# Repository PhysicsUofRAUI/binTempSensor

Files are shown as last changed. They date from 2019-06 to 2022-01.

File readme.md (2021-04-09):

# Bin Temperature Sensor
This project is a gadget to monitor the temperature in a grain bin. This is important because when grain heats it can spoil and a farmer can lose lots of money. The current iteration is the cheapest when 4 bins are wired up and costs about $140 per bin. That cost can be contrasted with the current bin monitoring systems which can cost up to $5000 a bin. The next iteration will focus on lowering the per bin cost for when more than 4 bins are wired up, and the iteration after that will integrate Arduino Cloud into the project, so that all collected data can be stored for later use.

## Main Hardware
### Arduino MKR 1400
This will be the Arduino that will send the alerts to the farmer and possibly one day send data to the Arduino Cloud. At the moment the code is designed to be controlled soley by the MKR 1400, but in the next iteration it will recieve alerts from regular Arduinos.

### Temperature Sensor
The DHT 22 or the DFR0198 sensor is currently being used as the sensor. Three of them are needed to monitor one bin.

### RF Link kits
The next iteration of the code will have the MKR 1400 recieve alerts from regular Arduinos about the sensors in the regular Arduinos.

### Arduino Mega
This will be used in the second iteration to control the sensors in the bin and send the alerts or data to the MKR 1400. 

## Implementations
### Current Implementation
The current iteration is simple, and only uses the MKR 1400 and the DHT 22 sensors or DFR0198 sensors. It will connect to the cloud and will request data every 15 minutes and if the temperature has changed the cloud will be updated. The frequency of readings can be reduced to save on data charges. This iteration is using the code located in code/ArduinoCloud.

#### Cost
Below I will outline the cost of how much the current implementation would cost for four large bins (about 30ft high). If your bins are larger or smaller you would either need to buy more or less wire, but it should not change the cost that much. The price of the wire put in is what I have got, but your price will probably be different.

#### Hardware Costs
##### With AM2302
| Item | Price of One | Number Needed | Total Cost |
| --- |:---:| ---:| ---:|
| MKR 1400 | [$103.41](https://www.digikey.ca/en/products/detail/arduino/ABX00018/8135631) | 1 | $103.41 |
| DHT 22 | [$21.81](https://www.digikey.ca/en/products/detail/adafruit-industries-llc/393/5356714?s=N4IgTCBcDaIIIFkAEYDMAGCBdAvkA) | 12 | $261.72 |
| Junction Box | [$25.99](https://www.amazon.ca/gp/product/B075DJQJVY/ref=ppx_yo_dt_b_asin_title_o00_s00?ie=UTF8&psc=1) | 1 | $25.99 |
| Wire (per foot) | Varies | 300 | $95 |
| Hologram Sim | [$5.00](https://store.hologram.io/store/) | 1 | $5.00 |
| Total | | | $491.12 |

Note that shipping was not included for any of this.

#### With DFR0198
| Item | Price of One | Number Needed | Total Cost |
| --- |:---:| ---:| ---:|
| MKR 1400 | [$103.41](https://www.digikey.ca/en/products/detail/arduino/ABX00018/8135631) | 1 | $103.41 |
| DFR0198 | [$10.03](https://www.digikey.ca/en/products/detail/dfrobot/DFR0198/7597054) | 12 | $120.36 |
| Junction Box | [$25.99](https://www.amazon.ca/gp/product/B075DJQJVY/ref=ppx_yo_dt_b_asin_title_o00_s00?ie=UTF8&psc=1) | 1 | $25.99 |
| Wire (per foot) | Varies | 300 | $95 |
| Hologram Sim | [$5.00](https://store.hologram.io/store/) | 1 | $5.00 |
| Total | | | $349.76 |

#### Monthly Costs
| Item | Price |
| --- |:---:|
| Arduino Cloud Account | [$9.00 CAD](https://store.arduino.cc/digital/create#) | 
| Hologram Data Costs | $11.80 CAD |
| Total | $20.8 |

Note: The data charges will probably be lower since this was calculated on costs when there was no grain in the bin and the temperature varies wildly then.

### Future Improvements
#### RF Link kits
The Arduino Mega has 54 digital pins so it can control many more bins than the MKR 1400 can, however, it cannot connect to the network. The RF link kit will allow the Mega to communication with the MKR 1400 and the MKR 1400 will be able to communicate with the network and send alerts.

#### Email Alerts
This is currently the focus of the work and it will entail the MKR GSM sending data to a third party, possibly IFTTT, which will then send out an email alerting the farmer to a temperature rise. 

# Contributing
Please anyone feel free to contribute. It would especially be appreciated if people with more experience on the hardware related, people involved on farms (like me :smiley:) who have experience to what is really needed to help production and save bushels, and people with experience writing software for this type of hardware.

All this being said I do want to stress that those thinking they don't know anything about this, but are still interested in the project please at least contact. We have almost no-one here and even if people don't think it they always have some sort of skill that could be used.

# Final Remarks
Hopefully this project becomes a success and maybe more like could be made!

Thanks for reading all this!

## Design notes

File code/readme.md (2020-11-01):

# Short Brief
This directory is meant to hold the code that will be deployed, or used to test the setup. Currently the deployment code is held in this very directory, instead of an inner directory, and the test code is held in the test directory. For this code to compile correctly it has to be run in the Arduino IDE. If the code is not run in the Arduino IDE the needed libraries will not be found please see the how-to docs to learn more.

## Deployment Code
### one_bin
This holds the code to control a single bin. Below is a table describing where Arduino is expecting all the sensors to be connected (a how-to doc will be written about sensor wiring).

| Pin | Location |
| --- | --- |
| 0 | Top of bin |
| 1 | Middle of bin |
| 2 | Bottom of bin |

### two_bins
This holds the code to control a two bins. Below is a table describing where Arduino is expecting all the sensors to be connected (a how-to doc will be written about sensor wiring).

| Pin | Location |
| --- | --- |
| 0 | Top of bin one |
| 1 | Middle of bin one |
| 2 | Bottom of bin one |
| 3 | Top of bin two |
| 4 | Middle of bin two |
| 5 | Bottom of bin two |

### three_bins
This holds the code to control a three bins. Below is a table describing where Arduino is expecting all the sensors to be connected (a how-to doc will be written about sensor wiring).

| Pin | Location |
| --- | --- |
| 0 | Top of bin one |
| 1 | Middle of bin one |
| 2 | Bottom of bin one |
| 3 | Top of bin two |
| 4 | Middle of bin two |
| 5 | Bottom of bin two |
| 6 | Top of bin three |
| 7 | Middle of bin three |
| 8 | Bottom of bin three |

### four_bins
This holds the code to control a four bins. Below is a table describing where Arduino is expecting all the sensors to be connected (a how-to doc will be written about sensor wiring).

| Pin  | Location |
| ---- | --- |
| 0 | Top of bin one |
| 1 | Middle of bin one |
| 2 | Bottom of bin one |
| 3 | Top of bin two |
| 4 | Middle of bin two |
| 5 | Bottom of bin two |
| 6 | Top of bin three |
| 7 | Middle of bin three |
| 8 | Bottom of bin three |
| 9 | Top of bin four |
| 10 | Middle of bin four  |
| 11 | Bottom of bin four  |

## Test Code
Currently there is only one test, and that one is a test of the custom library and this style of the code. A how-to doc will be included in the how_to_docs directory.

## Future Additions
When the new iterations are being developed new folders in the test directory will be included, and I will do my best to document what they are and what they are doing. Once deployment code has been developed for the new iterations new folders will appear to hold the deployment code so that the code for the different iterations are held separately.

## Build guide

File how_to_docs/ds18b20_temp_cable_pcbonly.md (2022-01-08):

# 1. Introduction
This how-to will hopefully explain to you how to create your own temperature cable to place within a bin using DS18B20 sensors. After completing the construction of the cables you can move on to put together the rest of the grain monitoring system outlined.

# 2. Needed skills, materials/tools, and parts
## 2.1 Skills
The only non-common/specialized skills needed to complete this how-to is hand soldering of wires and programming of Arduinos. A great tutorial on youtube can be seen here: https://www.youtube.com/watch?v=Zu3TYBs65FM. If you follow that guy you will solder better than I do.

For programming an Arduino I would recommend reading this article: If you have not done this before I would recommend reading the following article: https://www.digikey.ca/en/maker/blogs/2018/how-to-get-started-with-arduino.

## 2.2 Material/tools
You will need a standard fine tip **soldering iron** to do the soldering. I personally use a single temperature not so fine tipped soldering iron, but I should probably upgrade. Along with the soldering iron you will need **solder** I use 23 gauge solder, but a lower gauge would probably work.

You will also need a pair of **side cutters** to cut away the stray wires after assembling the board.

The last tool you will need is a pair of wire **strippers**.

## 2.3 Parts
- 4 DS18B20 sensors (https://www.digikey.ca/en/products/detail/adafruit-industries-llc/381/5875807)
- Some wire (https://www.homedepot.ca/product/southwire-18-3-fas-lvt-thermostat-wire-150m-brown/1000794341)
  - I used 60 ft of fire alarm cable for a 25ft tall bin

# 3. Assembly
## 3.1 Measure The Bin
The easiest way to do this is to measure the height of one ring and then count how many rings there are. In my case I measured one ring to be roughly 3.5 feet, and I counted 5 rings in total. That makes a total height of $3.5ft \times 5 = 17.5ft$.

To gauge how long the entire cable needs to be I estimated the height of the top to be 5ft to 8.5ft. That brings the total height estimate to 25ft so doubling that brings me to 50ft and then an extra 10ft gives some leeway to hook up the arduino later.

## 3.2 Decide where to place the sensors
Placing the sensors have to be done with some care. The top sensor should be in the top ring or lower so it is covered by the grain, and the bottom sensor needs to be somewhere around the start of the hopper but can not be at the bottom.

What I did initially was to place the bottom sensor first and then the space the other two 7ft away from each other. During operation it was realized that this did not give adequate coverage of the bin and it was decided to increase the amount of sensors to 4 and to place them 4ft apart.

Below is an outline of how my sensors should line up in the bin.

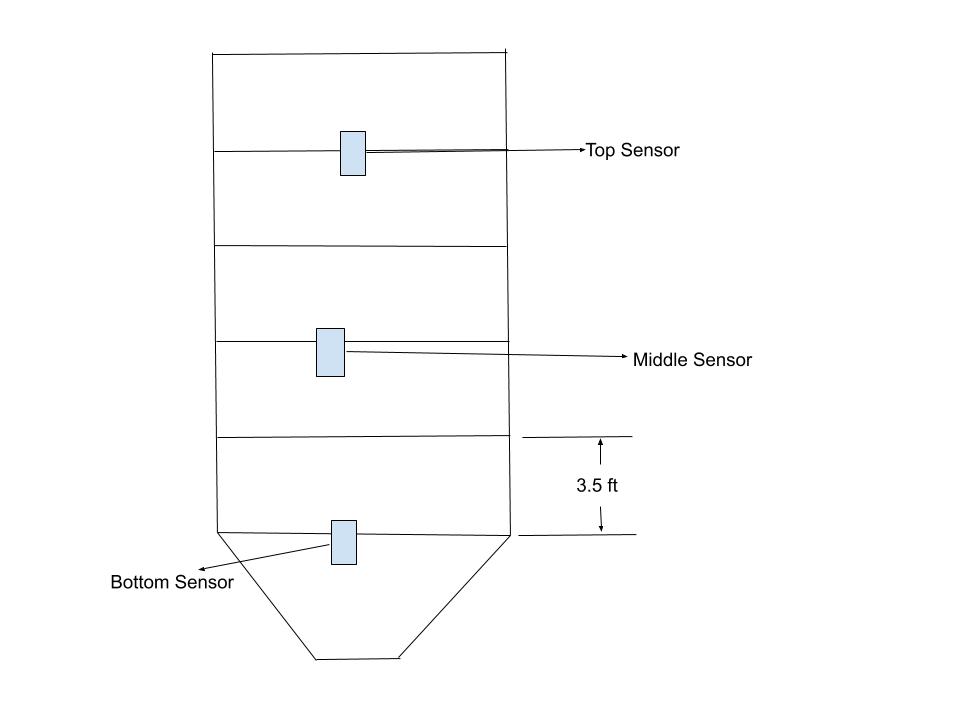
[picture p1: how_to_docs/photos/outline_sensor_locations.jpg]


## 3.3 Mark where the sensors go on the main cable
Before I started attaching the sensors I used a knife to mark the places where the sensors are to go. A photo can be seen below.

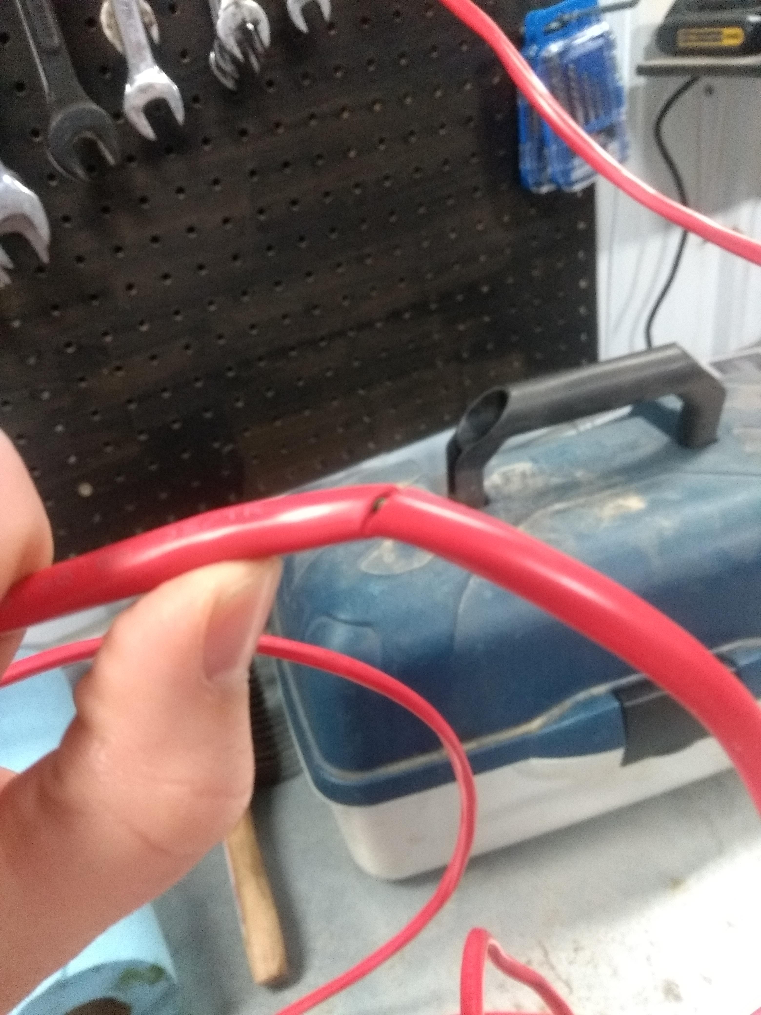
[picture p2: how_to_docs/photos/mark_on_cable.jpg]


When doing longer cables I would attach a sensor and then mark the next one just because it was getting to become cumbersome to deal with all the wire that was strewn around the shop.

## 3.4 Attach the sensors to the main cable
Before placing all the sensors on the cable it is advisable to slide three pieces of heat shrink (about 6 inches in length) onto the cable to be used later to cover up all the connections made while attaching the sensors.

### 3.4.1 Bottom Sensor
1. Strip the power (I used the red one) and the ground (I used the black one) just a enough so the sensor can be attached. To see the what the different colours of the DS18B20 sensors are I would go to the datasheet from that particular manufacturer. In the case of version linked above a table is provided below:

| Colour | Purpose |
| --- | --- |
| Blue | Ground  |
| Yellow | Data |
| Red | Power |

The only other colour I have seen is black for ground instead of blue.

2. Now strip the wire that will be used as the data pin.

3. Solder the black wire of the sensor to the ground.

4. Solder the red wire to the power.

5. Solder the last wire (yellow wire on my devices) to the conductor that will be used as the data wire.

6. Put some electrical tape around each of the solders.
  - Note: for this one heat shrink could be used, but for the following it could not

7. Apply the first heat shrink around the electrical connections. Do not heat the heat shrink until after the cable is tested in case something is wrong.



A photo of a DS18B20 sensor attached to the cable will be added later.

### 3.4.2 Middle and Top Sensor
1. Measure the decided amount of feet separating each sensor and mark the location.

2. Follow the steps done for the bottom sensor keeping in mind the sheathing will have to be cut away instead of stripped since it is in the middle of the cable.

Cable shown stripped in the middle.



The sensor soldered and attached in the middle.



The sensor tapped in the middle.





## 3.5 Test the Cable
### 3.5.1 Assemble the circuit
For this step you will need an assembled grain monitoring board, your freshly created cable, an MKR board, and a computer with the Arduino IDE installed. Plug the Arduino into the PCB and plug the cable into the female pluggable connector location with one of the male connectors (attach the male connector first). Below a photo shows the Arduino plugged in along with the male connector plugged into the female connector.

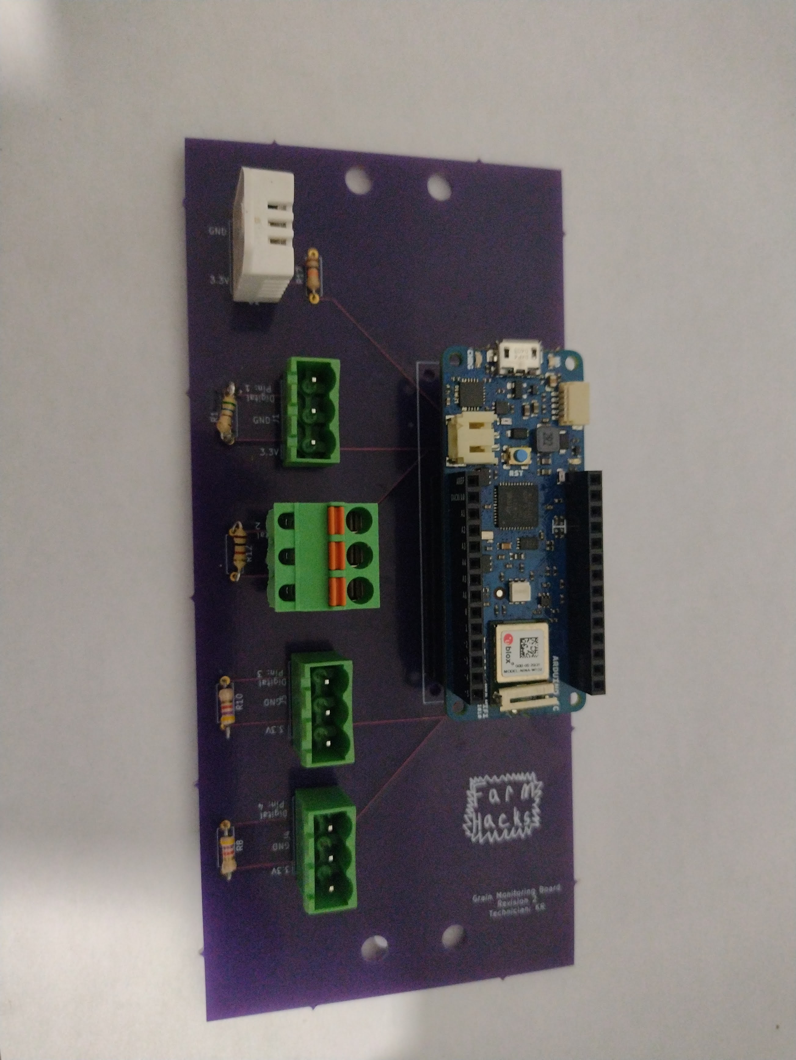
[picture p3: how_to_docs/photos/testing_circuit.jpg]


People more experienced with electronics can likely figure out other ways to assemble this circuit but I will not get into them here.

### 3.5.2 Edit Code
The code to be using can be found at code/testing_code. What needs to be added/changed is the device addresses on lines 24, 25, 26 and 27. Those lines are shown below:
```
DeviceAddress top = { 0x28, 0x63, 0x38, 0xF3, 0x4C, 0x20, 0x01, 0xD2 };
DeviceAddress middle_top = {  };
DeviceAddress middle_bottom = {  };
DeviceAddress bottom = {  };
```
The address labeled top is filled out as an example but it will have to be replaced with the address on the label that was on the top DS18B20s bag. Each of the other addresses will also have to be labeled.

### 3.5.3 Upload Code
Once the code is edited you will have to upload it to the Arduino.

### 3.5.4 Check the sensors
First open the serial monitor while the Arduino is plugged in to view the temperature the Arduino is reading. When it is open I would go and warm the individual sensors as they are running to ensure the sensors were placed in the correct locations.

## 3.6 Complete the Cable
If the testing went as planned take a heat gun (or a torch if you do not have one), and heat the heat shrink to seal the connections.

# 4. Conclusion
This concludes the tutorial of how to create the DS18B20 based temperature monitoring cable. I hope that my explanations were enough but if they weren't please open an issue in the GitHub or if you bought a kit you can reach out to me directly.

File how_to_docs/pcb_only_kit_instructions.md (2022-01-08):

# 1. Introduction
The following document will explain how to assemble the project that I initially created the custom PCB that you may have bought if you are reading this message. The PCB could be used for any project that uses sensors that require a pull up resistor and 3.3V power, and that leaves a lot of open area.

Given that the potential projects are so wide open I decided to just describe a project I have used it for and will leave it to others to use it for that project or others.

## 1.1 Description of Project
I initially created this board to allow easy and simplified wiring for my grain monitoring cables. I pursued this grain monitoring project because my dad is a farmer and he wanted to monitor the temperature of his grain, but he did not want to pay the big price for the commercial versions of these products.

The project consists of 4 cables with 4 DS18B20 sensors attached to each cable and then those cables are attached to the board that is in the kit. The board contains a slot where an MKR board can be attached and where it is attached the sensors get connected to it. I know that those two sentences probably sound very condensed and they are so if you want to know more keep reading!

The rest of the document will discuss assembling this project.

# 2. Needed skills, materials/tools, and parts
## 2.1 Skills
Experience with Arduino Cloud and the Arduino IDE would be very helpful in completing the following instructions, but are not strictly nescessary. Experience soldering PCBs and wires together would also be helpful but is not nescessary.

Links to tutorials are provided in the sections in which the skills are needed.

## 2.2 Material/tools
Here I will list the materials and tools that are nescessary to assemble the kit, but that I do not supply.

- Soldering Iron
- Solder
- Side-cutters
- Wire strippers
- Micro-USB cable
- Fire Alarm Cable (about 60 ft per 5000 bushel bin plus distance of enclosure to bin)
- Enclosure (https://www.amazon.ca/gp/product/B075DJQJVY/ref=ppx_yo_dt_b_asin_title_o05_s00)
  - any enclosure that can hold the PCB and wires will do, the amazon one linked is just the one I used.

### MKR Boards
I have decided not to include the MKR boards at this time to give you the flexibility to choose which one is best. In the Antenna tutorial I explain what to order for antennas when using the MKR 1400.

These are the two boards I have used:

1. MKR 1010 : https://www.digikey.ca/en/products/detail/arduino/ABX00023/9486713
  - best success
2. MKR 1400 : https://www.digikey.ca/en/products/detail/arduino/ABX00018/8135631
  - inconsistent connection when I used

### DS18B20 Sensors
For this version of the kit that does not have the DS18B20 sensors 16 of those are required to complete the project.

## 2.3 Parts Included In Kit
These are all the parts that I will be supplying in the kits being sold on Tindie.

1. 2 14 pos Stackable headers (https://www.digikey.ca/en/products/detail/sullins-connector-solutions/PPTC141LFBN-RC/810152)
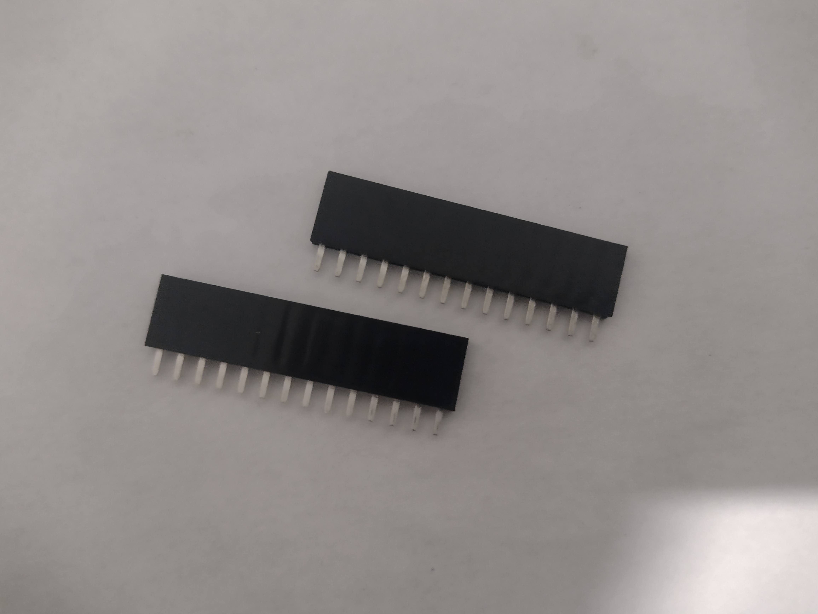
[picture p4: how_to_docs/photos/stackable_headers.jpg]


2. 4 pluggable PCB mountable connectors (https://www.digikey.ca/en/products/detail/te-connectivity-amp-connectors/2351885-3/10415935)
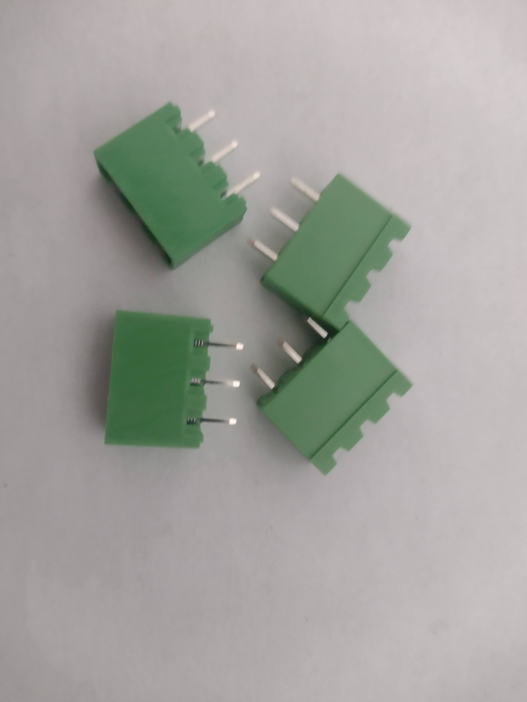
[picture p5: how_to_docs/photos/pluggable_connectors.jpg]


3. 4 560 Ohm to 4.7 K Ohm resistors (https://www.digikey.ca/en/products/detail/yageo/cfr-25jb-52-560r/2464)
  - difference in resistance values will be discussed (below are 560 Ohm resistors)

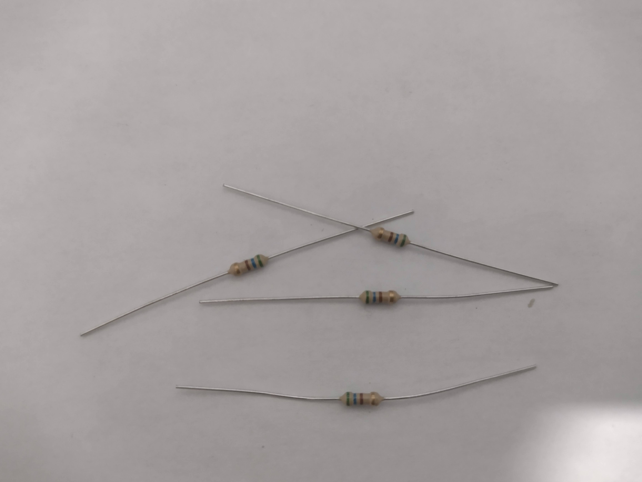
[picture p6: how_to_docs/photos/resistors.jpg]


4. 1 10K Ohm resistor (https://www.digikey.ca/en/products/detail/stackpole-electronics-inc/CF14JT10K0/1830374)
5. 1 DHT 22 sensor (https://www.digikey.ca/en/products/detail/adafruit-industries-llc/385/5774230)
  - below photo contains both the dht22 sensor and the 10K Ohm resistor

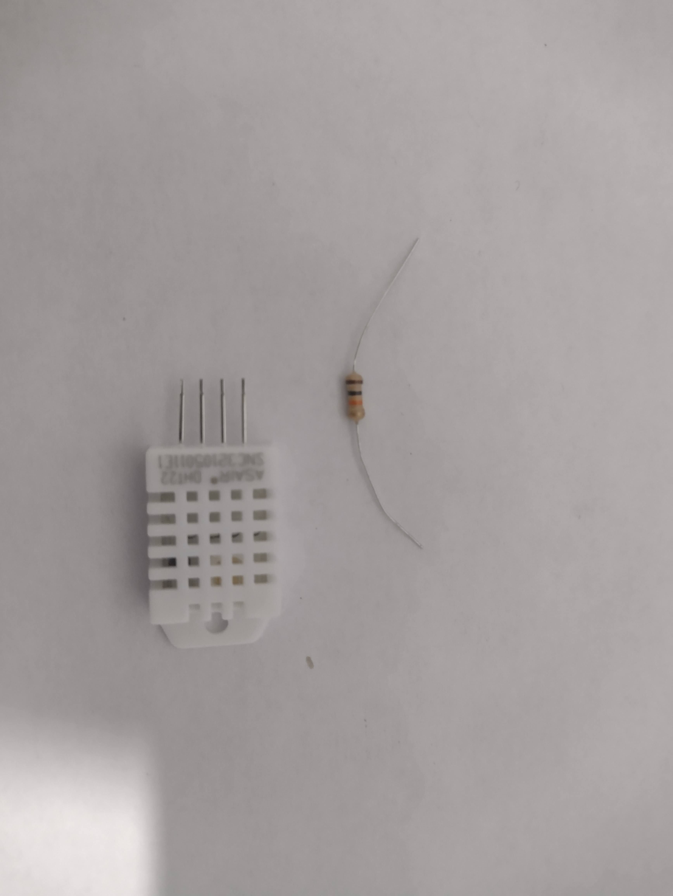
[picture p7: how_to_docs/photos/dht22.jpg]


6. Custom PCB created for this project (see the ecad folder)

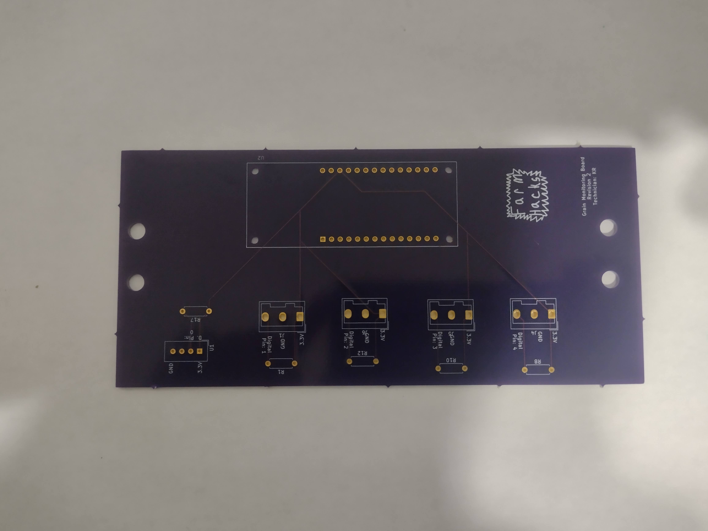
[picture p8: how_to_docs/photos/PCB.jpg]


7. 4 Terminal Plugs (https://www.digikey.ca/en/products/detail/te-connectivity-amp-connectors/2350397-3/10415914)

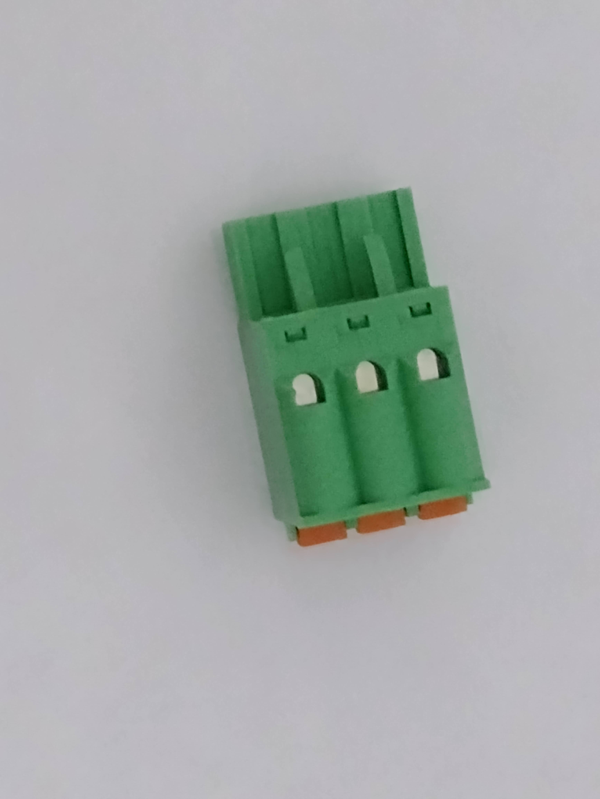
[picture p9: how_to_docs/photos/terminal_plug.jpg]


# 3. Location of the rest of the documents
I will be putting each separate document in the same location in the duotang (if you bought a kit), and I will outline that order here.

1. The overall outline (this document)
2. Address Logging
3. The PCB Assembly Document
4. The Temperature Cable Assembly Document
5. The Code Upload Document
6. Antenna Assembly Document

# 4. Suggested Assembly Order
## 4.1 PCB Assembly
The first thing I would do is assemble the PCB.

## 4.2 Temperature Cables
The second thing I would do would be to assemble the Temperature cables. This would include logging the one wire addresses of all the DS18B20 sensors that you have purchased.

## 4.3 Code Upload
The next step I would do would be to upload the code to the Arduino you choose to use.

## 4.4 Test Set Up
Now that everything is assembled I would plug each of the cables into the PCB and I would also plug in the Arduino to the board. The Arduino should be plugged in such that the micro-usb port is facing the end where the DHT 22 is located.

Hopefully, you marked the bin number for each cable and if so then you can plug in the cable into the corresponding plug on the board. The plugs should have a marking on the PCB that says 'Digital Pin: 1' and that number corresponds to the bin number.

Below is a photo of how the cable should look plugged in:
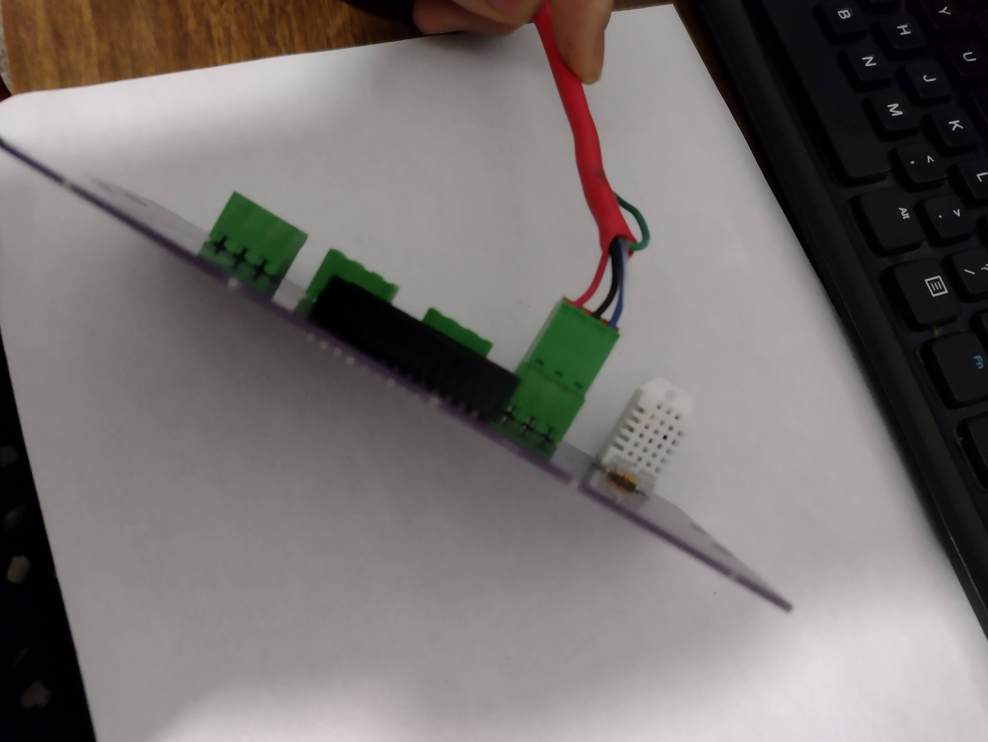
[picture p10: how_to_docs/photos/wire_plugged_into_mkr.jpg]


Note the wire colours and their locations. My blue wire was the data wire, black was ground, and red was 3.3V or power on the ds18b20.

Blue -> Digital Pin
Black -> GND
Red -> 3.3V

The PCB should have notes showing this.

The Arduino needs to be powered with a standard cell phone charger (5V).

When everything is plugged in you can check whether it is working by looking at your 'things' page and checking if the arduino is transmitting temperatures.

## 4.5 Install Cables in the Bin
I simply climbed to the top of the bin while empty and dropped the cable in while my dad stayed on the ground and looked inside the bin to tell me how close I was to the bottom. Once we had the sensors in what we thought were good locations I fastened the cable to the bin with zip ties. The cable has to be long enough to be fastened to the outside of the bin and then to reach the Arduino, and for me that was 60ft if the Arduino was directly below the bin and more if the Arduino was farther away.

I would do some measurements if you won't be placing the Arduino directly under the bin to get the correct cable measurements.

## 4.6 Place PCB in Enclosure and plug everything in
If you are using the enclosure I used then you will either have to buy some strain reliefs and pop the rubber stoppers out, or you can just drill/cut a hole in the stopper like I did. Using a strain relief or similar connector would be more professional.

Try to pop out as few of the rubber stoppers as possible. I was able to get away with cutting a hole in three of them. Two to allow the cables in and one to allow the micro usb in.

First I would plug in the cables into their correct places, and then I would plug in the cell phone charger to the Arduino.

## 4.7 Monitor Away
Now all that is done you should be able to sit back and monitor the grain temperature of the grain in the bins you just installed a cable in. A good next step would be to create a Dashboard to collect all the data you are collecting, a good tutorial for that can be found here: https://create.arduino.cc/projecthub/amalbanyus/create-a-dashboard-with-the-arduino-iot-cloud-1a897b

# 5. Conclusion
Thank you for reading and for purchasing the kit (if that is how you got this document). If you have any questions feel free to open an issue on the github, https://github.com/PhysicsUofRAUI/binTempSensor, or if you bought the kit you can reach out to me directly via email.

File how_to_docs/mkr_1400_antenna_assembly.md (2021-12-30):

# 1. Introduction
This short how-to will list the parts needed to some larger antennas to the MKR 1400 board. You do not need to read this if you are going to use the basic antenna such as, this one made by Arduino, https://www.digikey.ca/en/products/detail/arduino/X000016/7793242, or this one made by Adafruit, https://www.adafruit.com/product/1991.

I should note my knowledge of antennas is limited and I have not had consistent success with these antennas, but I did have trouble initially figuring out what parts were needed so I thought I'd include this to document my limited knowledge.

# 2. Needed skills, materials/tools, and parts
## 2.1 Skills
No specialized skills are needed for this.

## 2.2 Material/tools
No tools or materials are needed except for the parts that will be part of the final assembly.

## 2.3 Parts
If you bought a kit from me than the antenna made by Arduino will be included but these parts will not be. I would consider using these parts if you need a higher gain antenna, or if you want to place your antenna a far distance away from the enclosure.

1. One of the following (or a similar one):
  - Magnetic Base Antenna: https://www.digikey.ca/en/products/detail/taoglas-limited/GA-107-201111/2332671
  - Large Flat Patch Antenna: https://www.digikey.ca/en/products/detail/taoglas-limited/FXUB66-01-0150C/3877413
  - Others: Make sure it is sensitive to GSM frequencies and that it has a SMA Male end
2. RP-SMA to SMA (Female to Female) : https://www.digikey.ca/en/products/detail/linx-technologies-inc/CSA-RPSM-216-SAFB/1962866
3. U.FL (UMCC) to RP-SMA : https://www.digikey.ca/en/products/detail/adafruit-industries-llc/852/6827042

# 3. Assembly
1. Attach large antenna to "RP-SMA to SMA (Female to Female)"
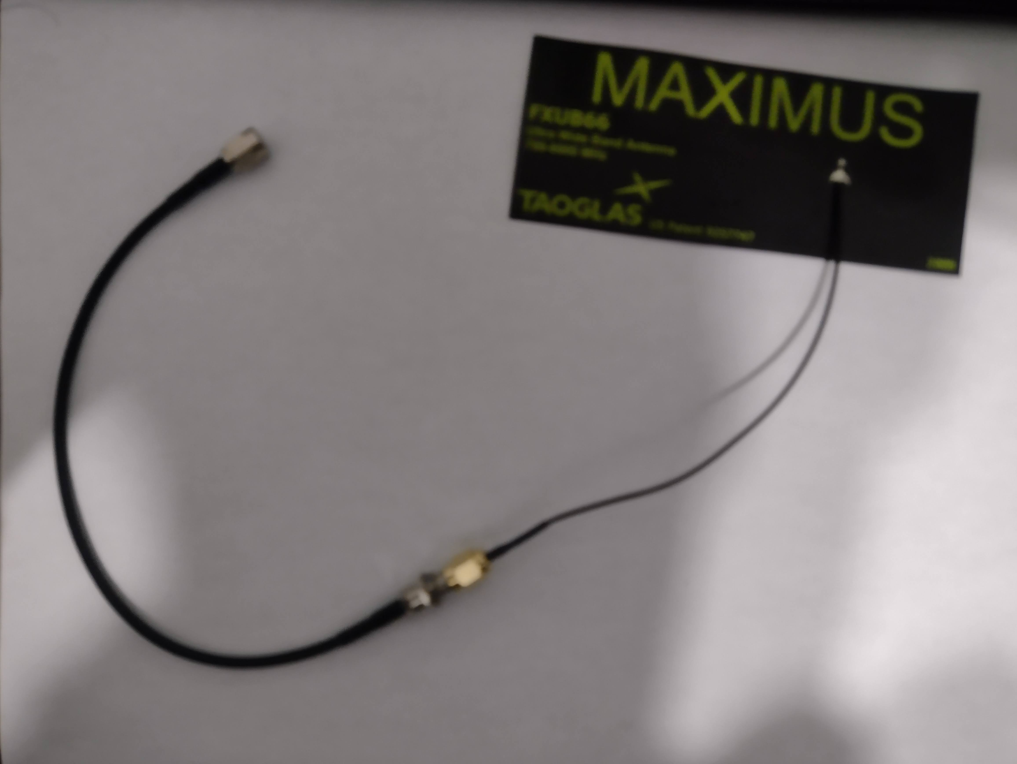
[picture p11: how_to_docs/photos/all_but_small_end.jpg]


2. Attach "U.FL (UMCC) to RP-SMA" to "RP-SMA to SMA (Female to Female)"
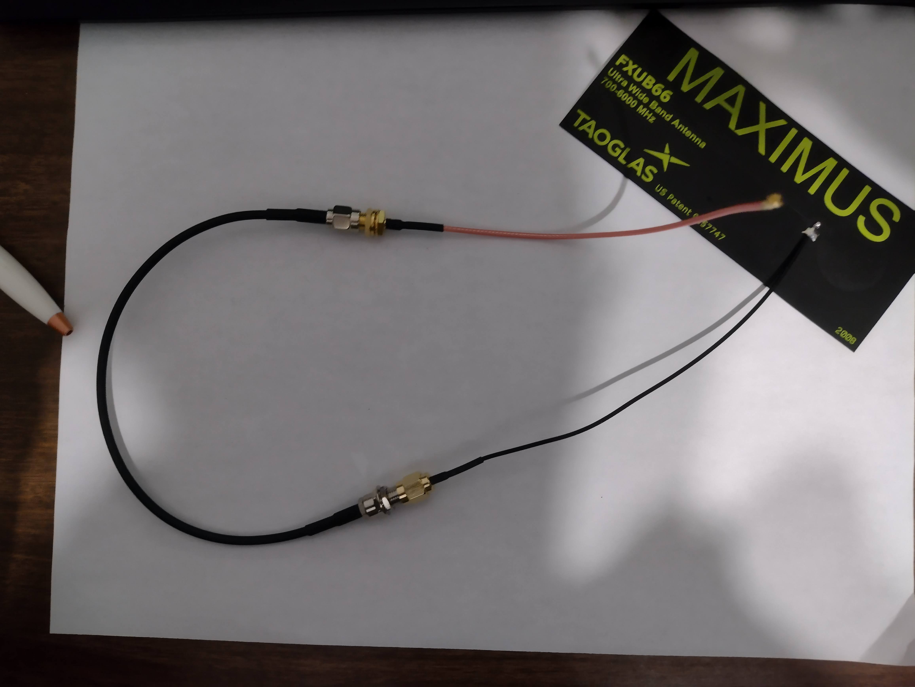
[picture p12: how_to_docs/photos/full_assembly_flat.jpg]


3. Attach to cable assembly to the Arduino and you have a your antenna ready
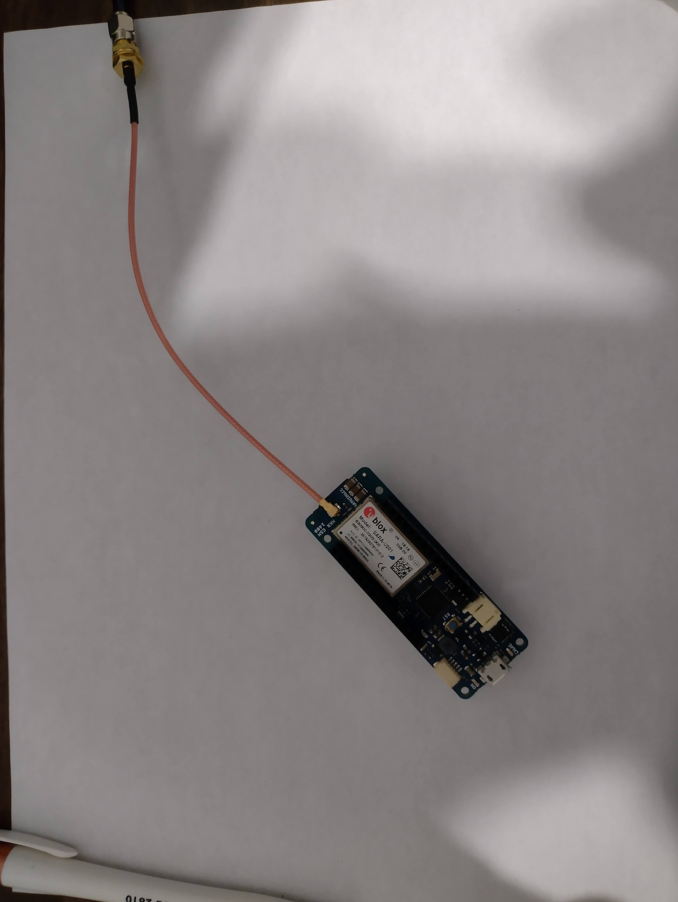
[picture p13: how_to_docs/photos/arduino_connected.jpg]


Special note is that the antenna attaches to the very small button looking thing on the Arduino MKR 1400 and sometimes you have to push the connector on, but it should go. 

# 4. Conclusion
This one is lacking on details I know, but that is because my knowledge is fairly limited and assembly wise it is pretty easy.

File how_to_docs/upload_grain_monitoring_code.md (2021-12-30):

# 1. Introduction
This how-to will show you one of many potential options for upload the code that will monitor your grain's temperature. This tutorial is supposed to go with the ds18b20 sensor cables that were covered in a previous how-to.

# 2. Needed skills, materials/tools, and parts
## 2.1 Skills
The most specialized skill needed to complete this how-to is programming an Arduino for use with Arduino IoT Cloud. Now it so happens to be that the main point of this how-to is to aquaint the reader with Arduino IoT Cloud so that they can upload the code to their chosen MKR board and monitor their grain. All that considered it would be helpful to have some experience with Arduino IoT Cloud and a good place to get that is at this link: https://docs.arduino.cc/cloud/iot-cloud/tutorials/iot-cloud-getting-started.

## 2.2 Material/tools
A **micro-usb charging cable** is needed to plug into the computer to program the Arduino MKR Boards. It may be that the first one you try will not work and if that is the case you will have to try a new one. Below is a photo of what I am talking about.

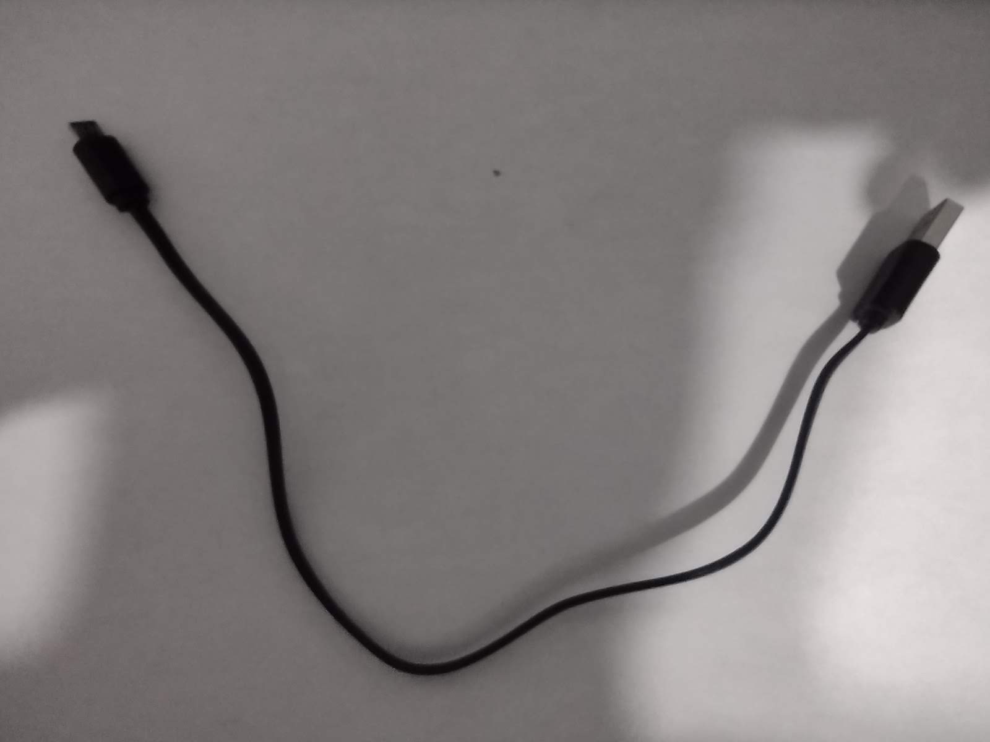
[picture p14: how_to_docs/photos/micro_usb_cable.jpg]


## 2.3 Parts
If you are using the MKR 1010 (WiFi) then all you will need is the board itself. If you are using the MKR 1400 (GSM) then you will also need an antenna of some sort. There is an antenna cable assemble how-to for the larger antennas, but most cases the a small antenna like the this one made by Arduino, https://www.digikey.ca/en/products/detail/arduino/X000016/7793242, or this one made by Adafruit, https://www.adafruit.com/product/1991.

# 3. Uploading
I am going to show one way to upload the needed code to an Arduino MKR board. Note that this is not the way that I do it, but I think it may be easier for people how have not had as much experience with Arduino.

The way I would do it is edit the thingProperties.h file and the .ino file and then upload it with the Arduino desktop editor.

## 3.1 Getting the Base Code
I am going to outline two different ways to access the code. The first way is the easiest if you have git installed and have experience with git. If you do not have git installed then I advise going the other way and download the zip file from the GitHub website that contains all this code.

Downloading the repository will also give you a digital copy of all these tutorials you are reading now. Using the git method is also a great way to get invovled in the project by making pull requests to the project (contact me for more information).

### 3.1.1 Cloning the Repo
If you have git installed you can clone the repo to you computer using
```
git clone https://github.com/PhysicsUofRAUI/binTempSensor
```

A more in depth explaination can be found on the git book's website here: https://git-scm.com/book/en/v2/Git-Basics-Getting-a-Git-Repository.

### 3.1.2 Downloading the Zip File
To download the zip file you have to follow the following steps:

1. Navigate to https://github.com/PhysicsUofRAUI/binTempSensor
2. Click on the 'Code' button on the repository's site. In the photo below it is the arrow labeled 1.
3. Click on download zip in the little pop up that comes out. In the photo below it is the arrow labeled 2.

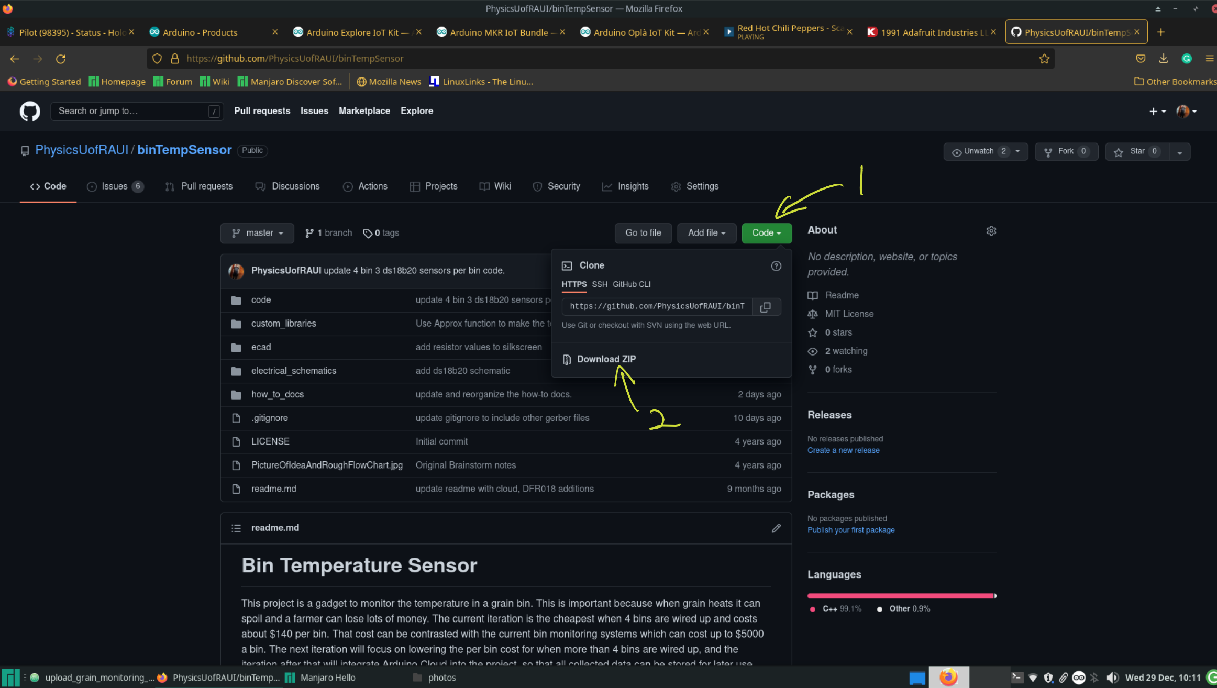
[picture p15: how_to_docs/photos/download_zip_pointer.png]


Now you should have the zip file and all that is needed to do is to unzip it to access the code within.

## 3.2 Add your own Addresses
In the code that is located in code/ArduinoCloud/four_bins_4_ds18b20/four_bins_4_ds18b20.ino you will need to add your own addresses. Open that file in a texteditor (ex. atom, notepad, and many others), and look at lines 47-50 below:

```
DeviceAddress one_top_address = { place your addresses in this area };
DeviceAddress one_middle_top_address = {  };
DeviceAddress one_middle_bottom_address = {  };
DeviceAddress one_bottom_address = {  };
```

Those four lines are declarations of four variables to hold the address of a one wire sensor. If you purchased a kit from me then you will have a bag labeled Bin One and it will contain four sensors labeled one_top, one_middle_top, one_middle_bottom, and one_bottom and on that label will be an address that looks like this { 0x28, 0x63, 0x38, 0xF3, 0x4C, 0x20, 0x01, 0xD2 }. If you have already constructed your cables then you should have you cables labeled with all the addresses.

What you have to do is write in the address in the area specified (where is says 'place your addresses in this area') for each of the addresses. For instance if your addresses are as follows:

one_top ->  0x28, 0x63, 0x38, 0xF3, 0x4C, 0x20, 0x01, 0xD2
one_middle_top ->  0x28, 0x64, 0x3B, 0xF3, 0x4F, 0x20, 0x01, 0xD2
one_middle_bottom ->  0x28, 0x34, 0xBB, 0xC3, 0x4F, 0x2B, 0x01, 0xD2
one_bottom ->  0x28, 0x3B, 0x4B, 0xC3, 0x2F, 0x2B, 0x01, 0xD2

Then the entries for bin one will look like:

```
DeviceAddress one_top_address = { 0x28, 0x63, 0x38, 0xF3, 0x4C, 0x20, 0x01, 0xD2 };
DeviceAddress one_middle_top_address = { 0x28, 0x64, 0x3B, 0xF3, 0x4F, 0x20, 0x01, 0xD2 };
DeviceAddress one_middle_bottom_address = { 0x28, 0x34, 0xBB, 0xC3, 0x4F, 0x2B, 0x01, 0xD2 };
DeviceAddress one_bottom_address = { 0x28, 0x3B, 0x4B, 0xC3, 0x2F, 0x2B, 0x01, 0xD2 };
```

This has to be done for each of the bins.

## 3.3 Create Your 'Thing' on Arduino Cloud
The first thing you need to do on the Arduino Cloud is log into or create your account at https://login.arduino.cc/login after that you need to go to the Arduino Cloud dashboard here https://create.arduino.cc/iot/things.

To create a new thing you first have to click the 'Create Thing' button. The photo below points it out, but note unless you have created things before your screen will not be showing anything like mine does.

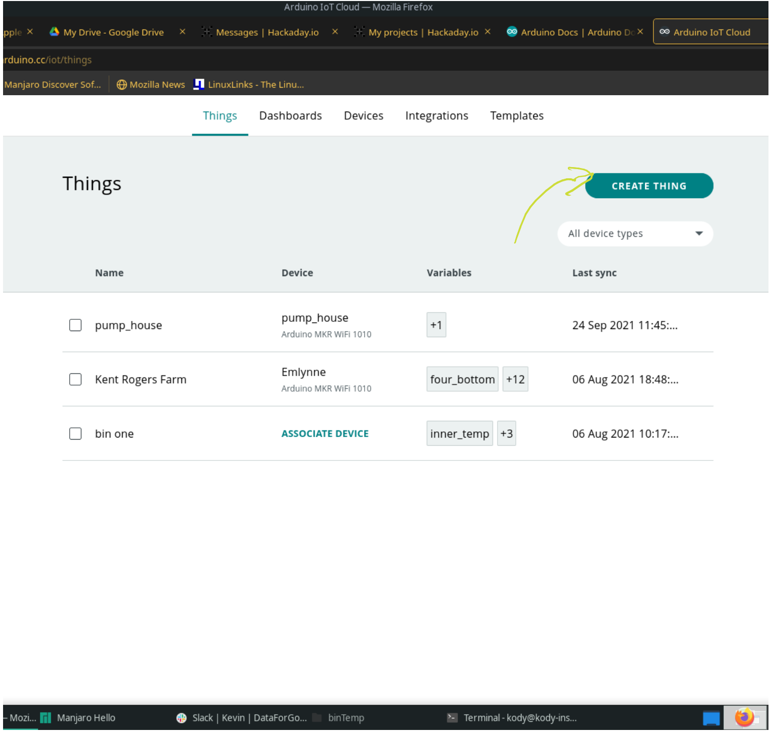
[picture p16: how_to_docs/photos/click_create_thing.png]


You can then name your thing like I have started in the photo below:

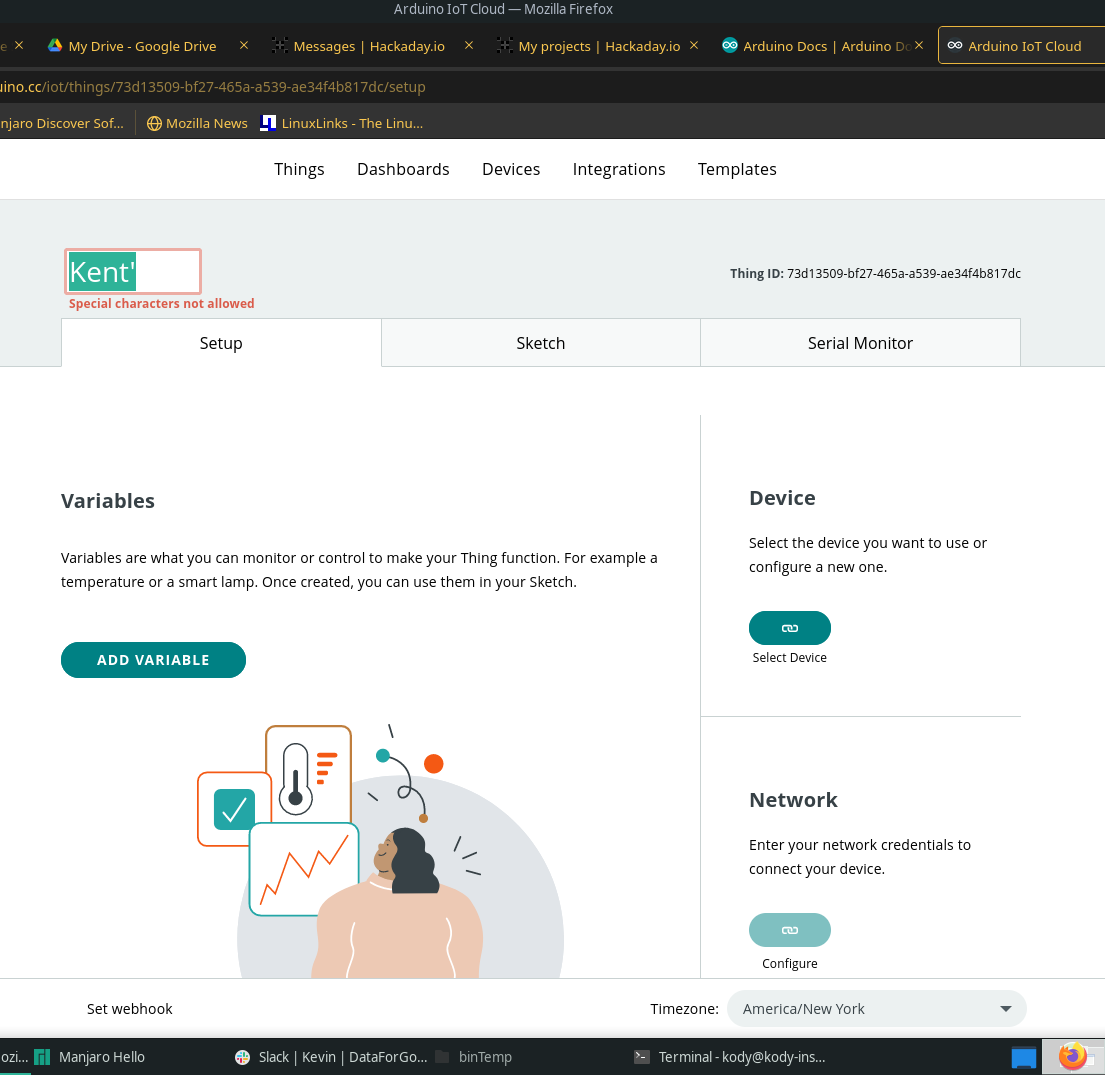
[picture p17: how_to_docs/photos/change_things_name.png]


## 3.4 Add all the Variables
Next step is to add all the variables needed. To start click the button 'Add Variable' as shown below.

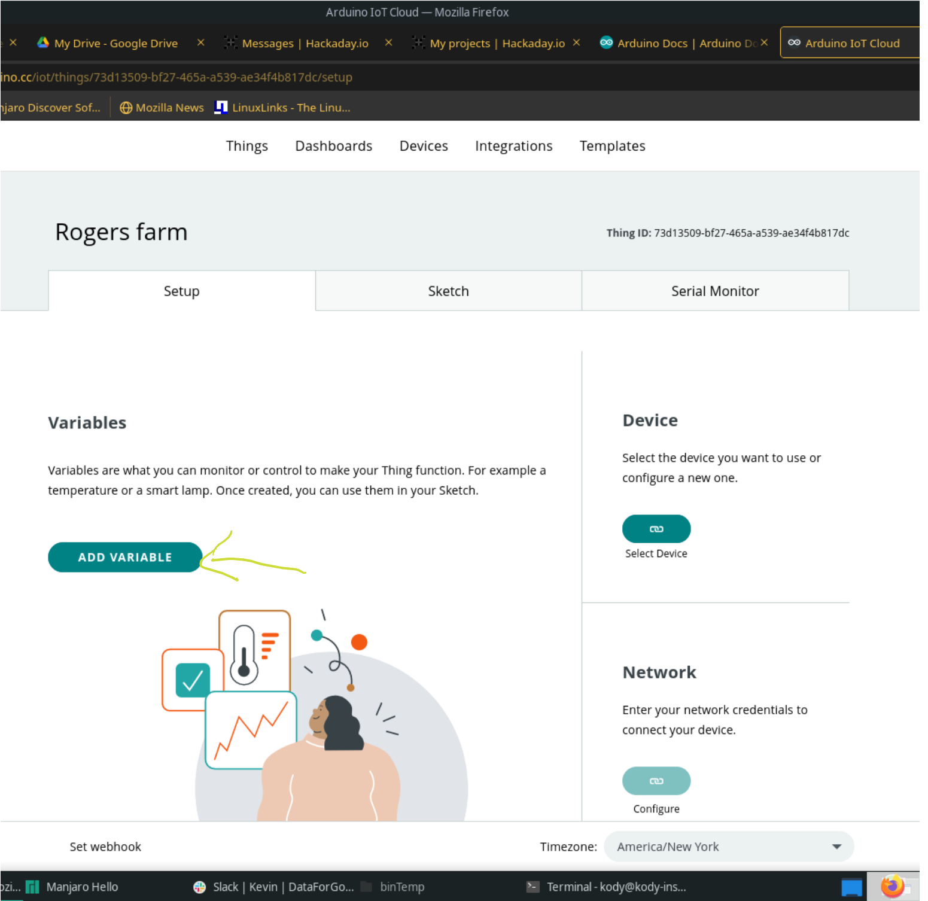
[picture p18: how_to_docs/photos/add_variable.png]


After that you need to fill the properties with the following:

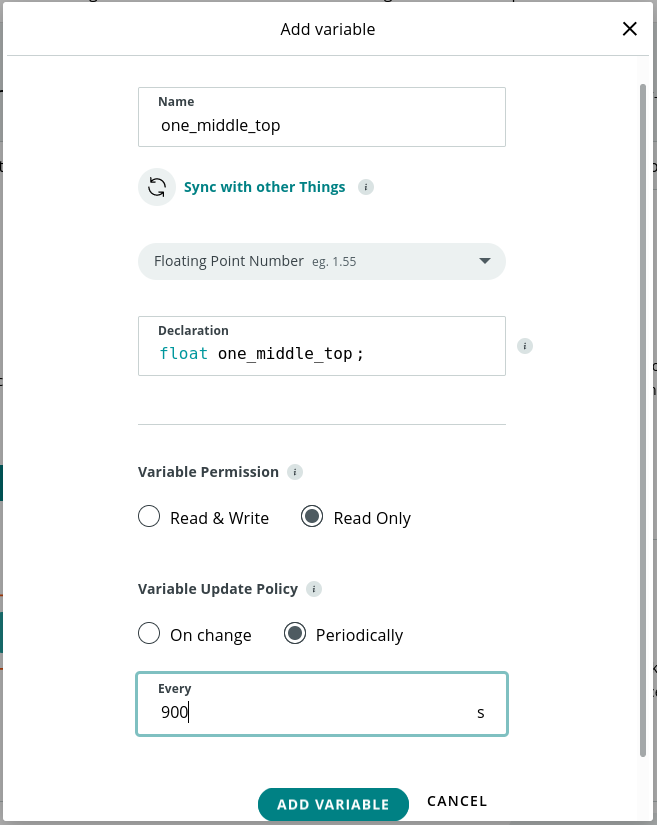
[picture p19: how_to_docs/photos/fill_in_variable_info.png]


The variables that need to be added for this tutorial are:

```
pcb_temp

one_top
one_middle_top
one_middle_bottom
one_bottom

two_top
two_middle_top
two_middle_bottom
two_bottom

three_top
three_middle_top
three_middle_bottom
three_bottom

four_top
four_middle_top
four_middle_bottom
four_bottom
```

And they all have the same parameters as in the earlier photo.

## 3.5 Attach Your Device
To attach a device you need to click the 'Select Device' button as shown below:

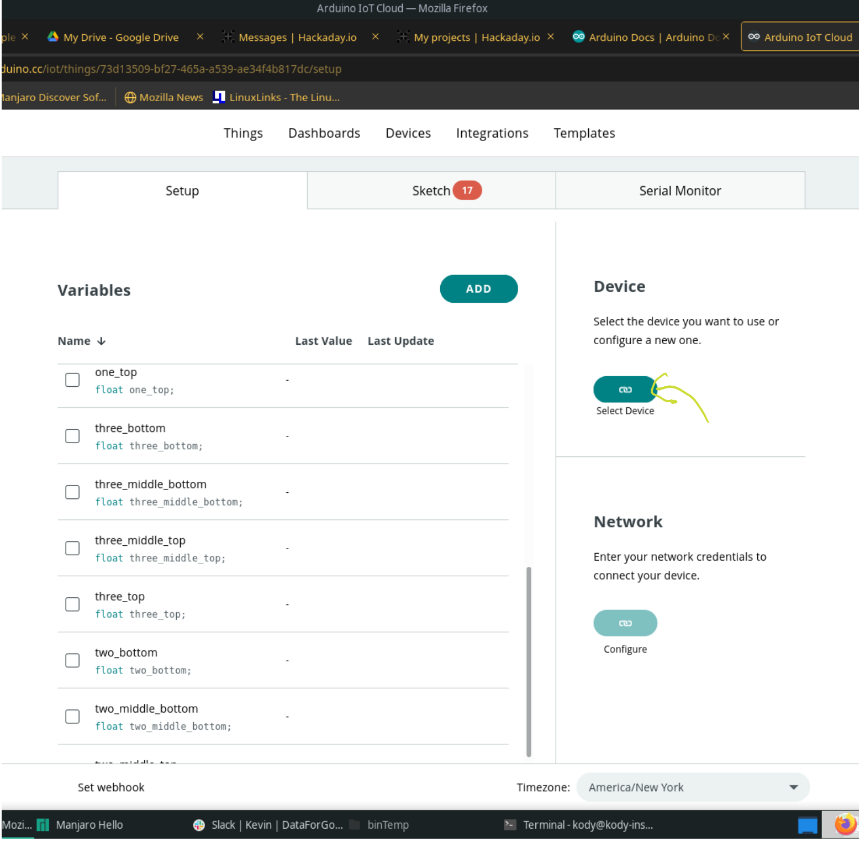
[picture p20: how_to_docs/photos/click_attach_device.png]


If you have not attached a device before here is a good article on how to do that: https://support.arduino.cc/hc/en-us/articles/360016495559-How-to-add-Arduino-devices-to-the-Arduino-IoT-cloud

## 3.6 Fill In Your Secret Tab
From your new thing's page you need to click 'Sketch' and then click 'Open full editor'. From the full editor you need to click the 'Secret' tab and then you should be brought to a screen like below:

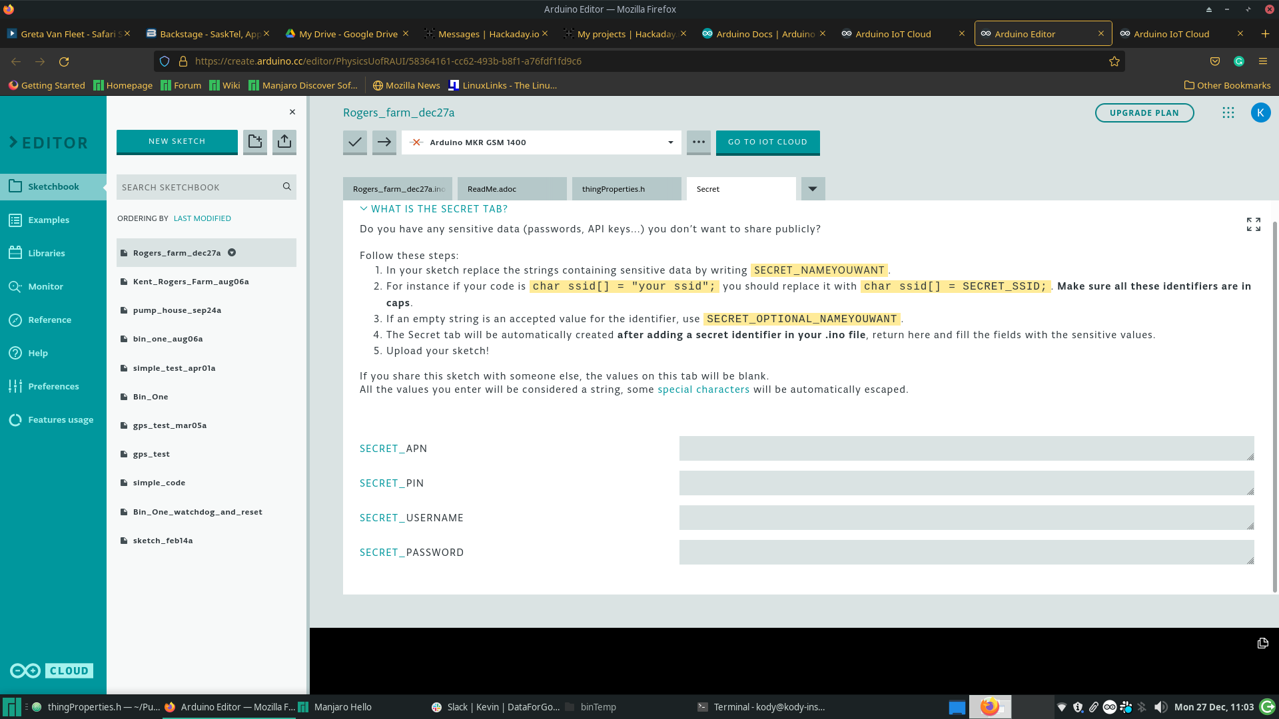
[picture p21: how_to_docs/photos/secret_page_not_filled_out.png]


This particular page is for the MKR GSM 1400. Below I show what it looks like when the network name and pin are filled out:

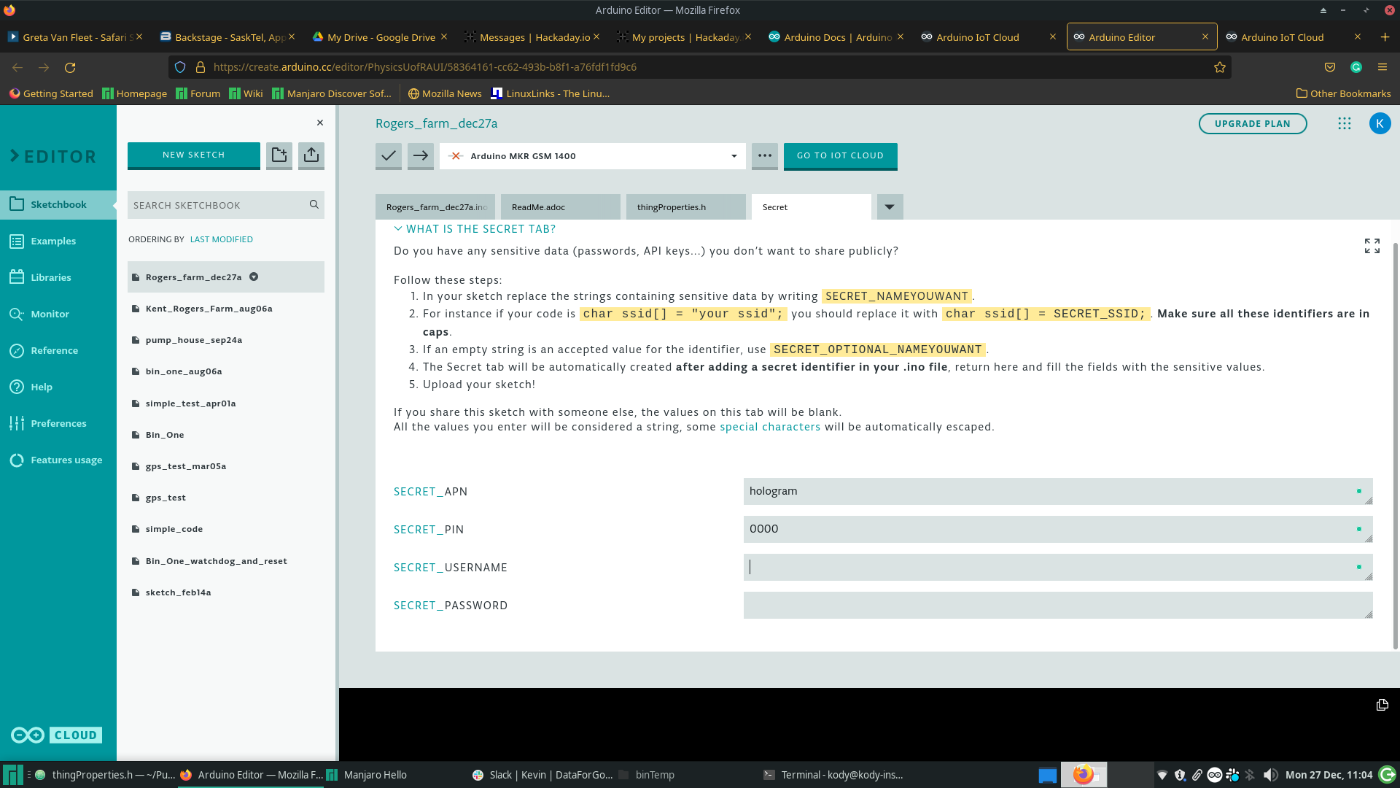
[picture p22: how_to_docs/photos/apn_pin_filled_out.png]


It will look different if you are filling it out for the MKR 1010

## 3.7 Copy the code to the .ino tab
Navigate to the .ino tab on the screen its name should be called 'your-things-name_date.ino'. Now copy all the code from the page you edited earlier and paste it over the code in that tab.

I would not touch the thingProperties.h tab since Arduino should have filled that out for you.

# 4. Conclusion
Your Arduino should now have the code to monitor your bins running on it.

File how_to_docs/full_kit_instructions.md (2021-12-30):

# 1. Introduction
In the following document I will outline the steps I would take to assemble the grain monitoring kit that either you have bought from me or have went ahead and sourced the materials yourself and are now assembling. Either option is good with me.

# 2. Needed skills, materials/tools, and parts
## 2.1 Skills
Experience with Arduino Cloud and the Arduino IDE would be very helpful in completing the following instructions, but are not strictly nescessary. Experience soldering PCBs and wires together would also be helpful but is not nescessary.

Links to tutorials are provided in the sections in which the skills are needed.

## 2.2 Material/tools
Here I will list the materials and tools that are nescessary to assemble the kit, but that I do not supply.

- Soldering Iron
- Solder
- Side-cutters
- Wire strippers
- Micro-USB cable
- Fire Alarm Cable (about 60 ft per 5000 bushel bin plus distance of enclosure to bin)
- Enclosure (https://www.amazon.ca/gp/product/B075DJQJVY/ref=ppx_yo_dt_b_asin_title_o05_s00)
  - any enclosure that can hold the PCB and wires will do, the amazon one linked is just the one I used.

### MKR Boards
I have decided not to include the MKR boards at this time to give you the flexibility to choose which one is best. In the Antenna tutorial I explain what to order for antennas when using the MKR 1400.

These are the two boards I have used:

1. MKR 1010 : https://www.digikey.ca/en/products/detail/arduino/ABX00023/9486713
  - best success
2. MKR 1400 : https://www.digikey.ca/en/products/detail/arduino/ABX00018/8135631
  - inconsistent connection when I used

## 2.3 Parts Included In Kit
These are all the parts that I will be supplying in the kits being sold on Tindie.

1. 2 14 pos Stackable headers (https://www.digikey.ca/en/products/detail/sullins-connector-solutions/PPTC141LFBN-RC/810152)


2. 4 pluggable PCB mountable connectors (https://www.digikey.ca/en/products/detail/te-connectivity-amp-connectors/2351885-3/10415935)


3. 4 560 Ohm to 4.7 K Ohm resistors (https://www.digikey.ca/en/products/detail/yageo/cfr-25jb-52-560r/2464)
  - difference in resistance values will be discussed (below are 560 Ohm resistors)



4. 1 10K Ohm resistor (https://www.digikey.ca/en/products/detail/stackpole-electronics-inc/CF14JT10K0/1830374)
5. 1 DHT 22 sensor (https://www.digikey.ca/en/products/detail/adafruit-industries-llc/385/5774230)
  - below photo contains both the dht22 sensor and the 10K Ohm resistor



6. Custom PCB created for this project (see the ecad folder)



7. 16 waterproof DS18B20 sensors (https://www.digikey.ca/en/products/detail/adafruit-industries-llc/381/5875807)
  - I will probably source from Alibaba since it is cheaper in bulk, but in the past I have used digikey.

8. 4 Terminal Plugs (https://www.digikey.ca/en/products/detail/te-connectivity-amp-connectors/2350397-3/10415914)



The DS18B20 sensors will be packaged into separate bags containing 4 which will encompass one bin. In each of those larger bags the fours sensors will each be separated into separate bags each with a label giving its one-wire address and where it should be located on the cable.

# 3. Location of the rest of the documents
I will be putting each separate document in the same location in the duotang (if you bought a kit), and I will outline that order here.

1. The overall outline (this document)
2. The Temperature Cable Assembly Document
3. The PCB Assembly Document
4. The Code Upload Document
5. Antenna Assembly Document

# 4. Suggested Assembly Order
## 4.1 Temperature Cables
The first thing I would do would be to assemble the Temperature cables. This is because I think it would lessen the chance that the sensors would get mixed up, and that it can be done before anything else.

## 4.2 PCB Assembly
After the cables have been assembled I would then proceed with assembling the custom PCB.

## 4.3 Code Upload
The next step I would do would be to upload the code to the Arduino you choose to use.

## 4.4 Test Set Up
Now that everything is assembled I would plug each of the cables into the PCB and I would also plug in the Arduino to the board. The Arduino should be plugged in such that the micro-usb port is facing the end where the DHT 22 is located.

Hopefully, you marked the bin number for each cable and if so then you can plug in the cable into the corresponding plug on the board. The plugs should have a marking on the PCB that says 'Digital Pin: 1' and that number corresponds to the bin number.

Below is a photo of how the cable should look plugged in:


Note the wire colours and their locations. My blue wire was the data wire, black was ground, and red was 3.3V or power on the ds18b20.

Blue -> Digital Pin
Black -> GND
Red -> 3.3V

The PCB should have notes showing this.

The Arduino needs to be powered with a standard cell phone charger (5V).

When everything is plugged in you can check whether it is working by looking at your 'things' page and checking if the arduino is transmitting temperatures.

## 4.5 Install Cables in the Bin
I simply climbed to the top of the bin while empty and dropped the cable in while my dad stayed on the ground and looked inside the bin to tell me how close I was to the bottom. Once we had the sensors in what we thought were good locations I fastened the cable to the bin with zip ties. The cable has to be long enough to be fastened to the outside of the bin and then to reach the Arduino, and for me that was 60ft if the Arduino was directly below the bin and more if the Arduino was farther away.

I would do some measurements if you won't be placing the Arduino directly under the bin to get the correct cable measurements.

## 4.6 Place PCB in Enclosure and plug everything in
If you are using the enclosure I used then you will either have to buy some strain reliefs and pop the rubber stoppers out, or you can just drill/cut a hole in the stopper like I did. Using a strain relief or similar connector would be more professional.

Try to pop out as few of the rubber stoppers as possible. I was able to get away with cutting a hole in three of them. Two to allow the cables in and one to allow the micro usb in.

First I would plug in the cables into their correct places, and then I would plug in the cell phone charger to the Arduino.

## 4.7 Monitor Away
Now all that is done you should be able to sit back and monitor the grain temperature of the grain in the bins you just installed a cable in. A good next step would be to create a Dashboard to collect all the data you are collecting, a good tutorial for that can be found here: https://create.arduino.cc/projecthub/amalbanyus/create-a-dashboard-with-the-arduino-iot-cloud-1a897b

# 5. Conclusion
Thank you for reading and for purchasing the kit (if that is how you got this document). If you have any questions feel free to open an issue on the github, https://github.com/PhysicsUofRAUI/binTempSensor, or if you bought the kit you can reach out to me directly via email.

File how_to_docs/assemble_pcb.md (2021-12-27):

# 1. Introduction
This document will hopefully give enough instructions so that anyone who reads it could assemble the PCB in question as long as they have enough experience soldering.

# 2. Needed skills, materials/tools, and parts
## 2.1 Skills
The only non-common/specialized skill needed to complete this assembly is hand soldering of electronics. A good tutorial on instructables can be found here: https://www.instructables.com/How-to-Assemble-a-Printed-Circuit-Board-PCB/.

As said in the tutorial I would recommend practicing with some resistors and a solderable breadboard if you have never soldered before. A solderable breadboard available on digikey can be found here: https://www.digikey.ca/en/products/detail/sparkfun-electronics/PRT-08808/7387401.

## 2.2 Material/tools
You will need a standard fine tip **soldering iron** to do the soldering. I personally use a single temperature not so fine tipped soldering iron, but I should probably upgrade. Along with the soldering iron you will need **solder** I use 23 gauge solder, but a lower gauge would probably work.

You will also need a pair of **side cutters** to cut away the stray wires after assembling the board.

## 2.3 Parts
If you are reading this document in a kit that you bought then all of the following parts should be included. If you did not buy a kit then you can order all of the parts from digikey with the links beside the items, but the PCB you would have to use the files in the ecad folder to order your own custom PCB.

1. 2 14 pos Stackable headers (https://www.digikey.ca/en/products/detail/sullins-connector-solutions/PPTC141LFBN-RC/810152)


2. 4 pluggable PCB mountable connectors (https://www.digikey.ca/en/products/detail/te-connectivity-amp-connectors/2351885-3/10415935)


3. 4 560 Ohm to 4.7 K Ohm resistors (https://www.digikey.ca/en/products/detail/yageo/cfr-25jb-52-560r/2464)
  - difference in resistance values will be discussed (below are 560 Ohm resistors)



4. 1 10K Ohm resistor (https://www.digikey.ca/en/products/detail/stackpole-electronics-inc/CF14JT10K0/1830374)
5. 1 DHT 22 sensor (https://www.digikey.ca/en/products/detail/adafruit-industries-llc/385/5774230)
  - below photo contains both the dht22 sensor and the 10K Ohm resistor



6. Custom PCB being explained in this tutorial (see the ecad folder)



# 3. Assembly
## 3.1 14 pos Stackable Headers
The first thing I would solder on would be the stackable headers, which are shown below on the PCB. To solder them you will have to flip the board upside down from what was shown in the photo, and with the current design you'd have to prop it up with something so it does not tip.

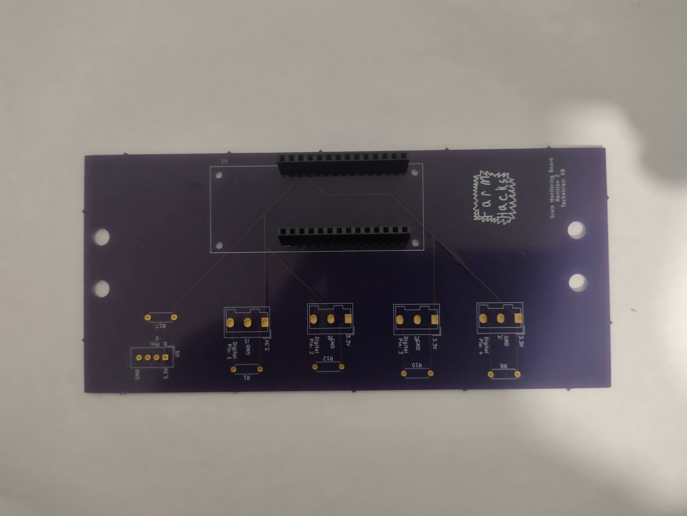
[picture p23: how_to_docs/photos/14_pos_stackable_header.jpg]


## 3.2 Pluggable PCB Mountable Connectors
Next can be either the PCB Mountable connectors or the resistors. Shown below are the PCB mountable connectors being put on before the resistors. This could make it hard to solder both the top and bottom of the resistors, but I usually only sodlder the bottom.

Note the orientation of the connectors since that is the orientation I will assume in later documents that people used.

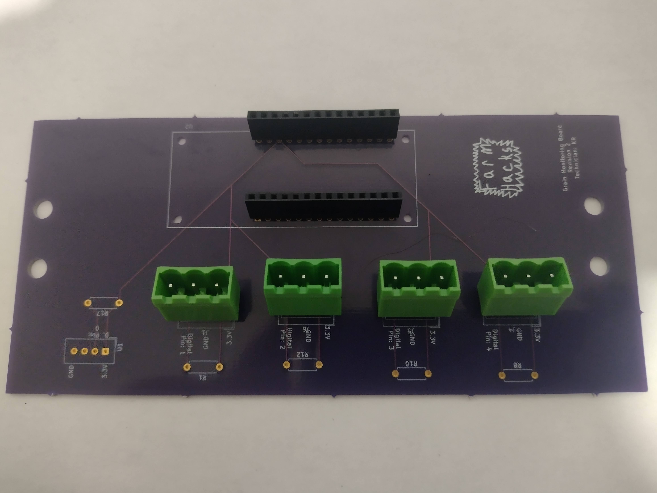
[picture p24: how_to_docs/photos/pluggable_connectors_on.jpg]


## 3.3 All Resistors
The resistors shown here are all 560 Ohm resistors, but resistors up to 4.7 K Ohm can be used depending on how far away your particular bins are. The further away they are the lower the resistance value you have to use, and this is because of how the DS18B20 sensors communicate. If in doubt use the lower resistance value in this case. More can be read here: https://learn.sparkfun.com/tutorials/pull-up-resistors/all, and another place is here https://www.electronics-tutorials.ws/logic/pull-up-resistor.html.

Below shows all the resistors being added to the PCB. The orientation of the resistors do not matter here.

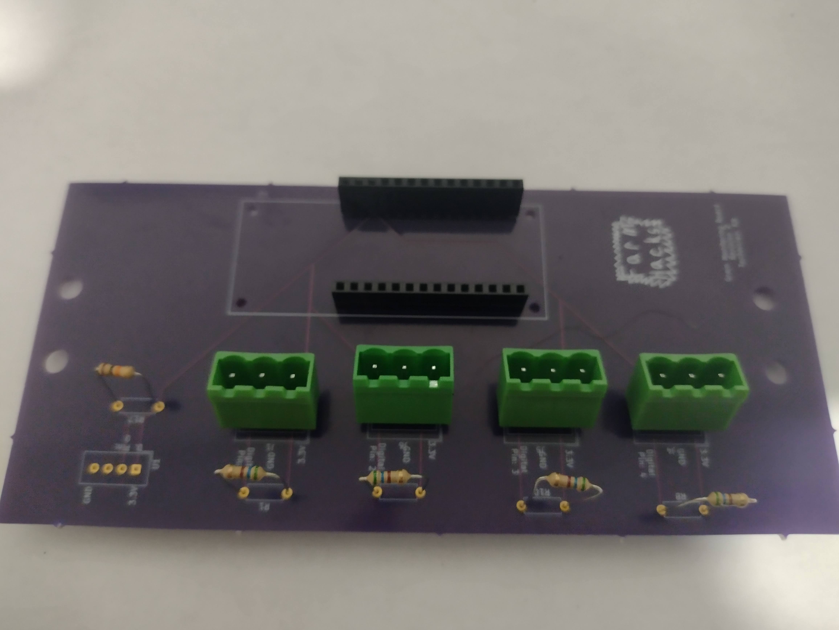
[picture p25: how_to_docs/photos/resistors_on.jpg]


## 3.4 DHT 22 Sensor
The last put to add is the DHT 22 sensor. The orientation of this one is critical since it will not work the other way. If you look at the PCB the pin values of the DHT are also labeled, so use them as a guide as well.

Extra info about the DHT22 sensor: https://learn.adafruit.com/dht

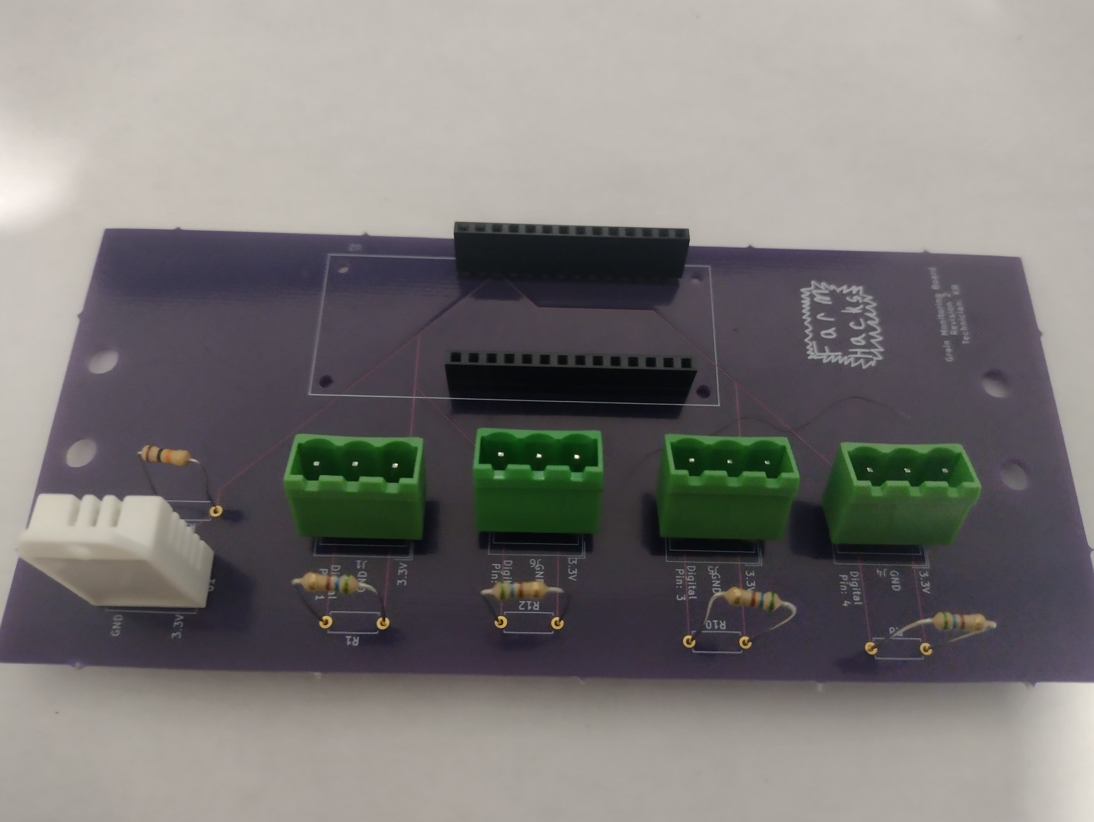
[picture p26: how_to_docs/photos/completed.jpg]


## 3.5 Cut Away Stray wires
The last step is to cut away the stray wires that are at the bottom of the board. I would cut the stray wires from the resistors, and trim the wires coming from the DHT 22.

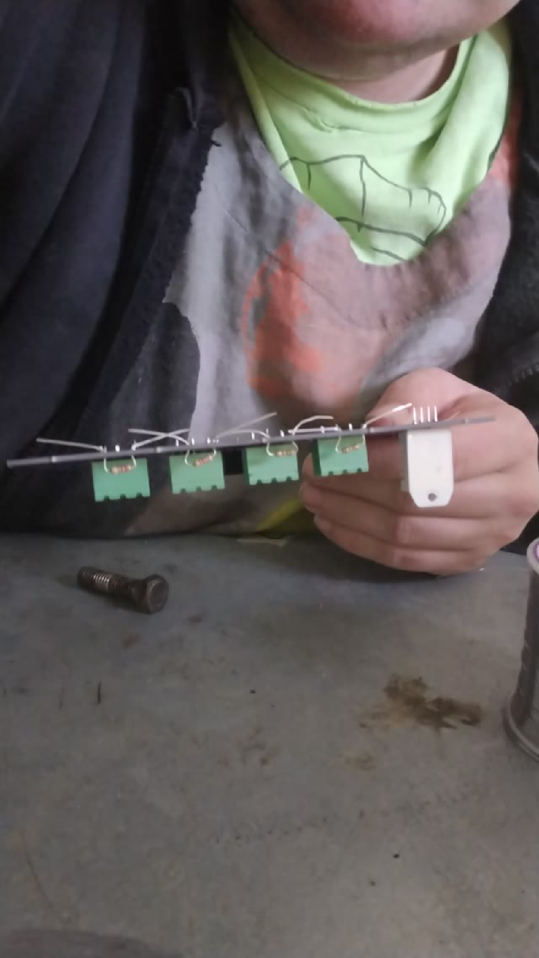
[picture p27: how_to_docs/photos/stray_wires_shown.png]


# 4. Conclusion
Well I hope this document was enough to guide you in assembling the grain sensor PCB board. If not you can make an issue in the github, or if you bought a kit from me you can reach out directly.

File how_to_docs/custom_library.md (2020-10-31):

# Purpose of this document
This document is meant to explain how to setup the custom library that was created so that the code provided in this repo will compile in the Arduino IDE. It also meant to explain how to run the tests in case someone wants to.

## 'Installing' the library
Follow these steps so that the Arduino IDE will know of the custom library that has been built.

1. Locate the libraries directory for Arduino.
 - on my machine it is found in '~/snap/arduino/41/Arduino/libraries'
 - for more information check out this article https://www.arduino.cc/en/hacking/libraries
2. Create a new directory called 'bin_sensor_library'
3. Copy the file 'custom_libraries/bin_sensor_library/bin_sensor.hpp' to the newly created directory
4. The code should now compile in your Arduino IDE

## Running the Tests
Follow these steps to run the tests

1. Install [CMake](https://cmake.org/) if not already installed.
2. Open terminal
3. Navigate to the custom_libraries directory in this project
4. Run `make clean` to remove any previous compilations
5. Run `make` to compile the tests
6. Run `./bin/DHT_U` to test the mock library
7. Run `./bin/bin_sensor` to test the custom library

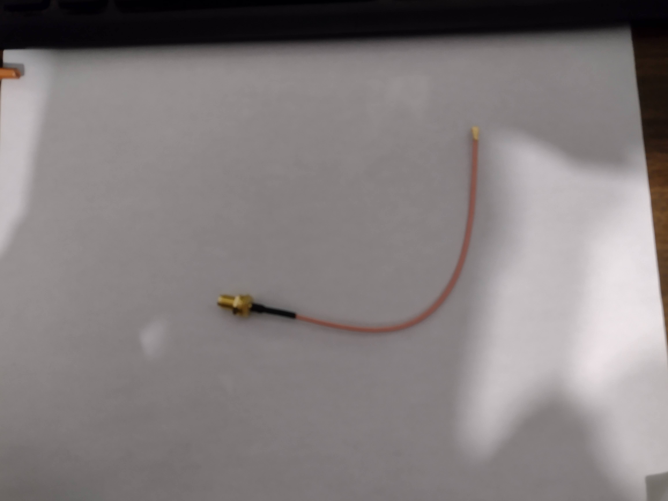
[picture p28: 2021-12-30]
how_to_docs/photos/small_end_to_large.jpg

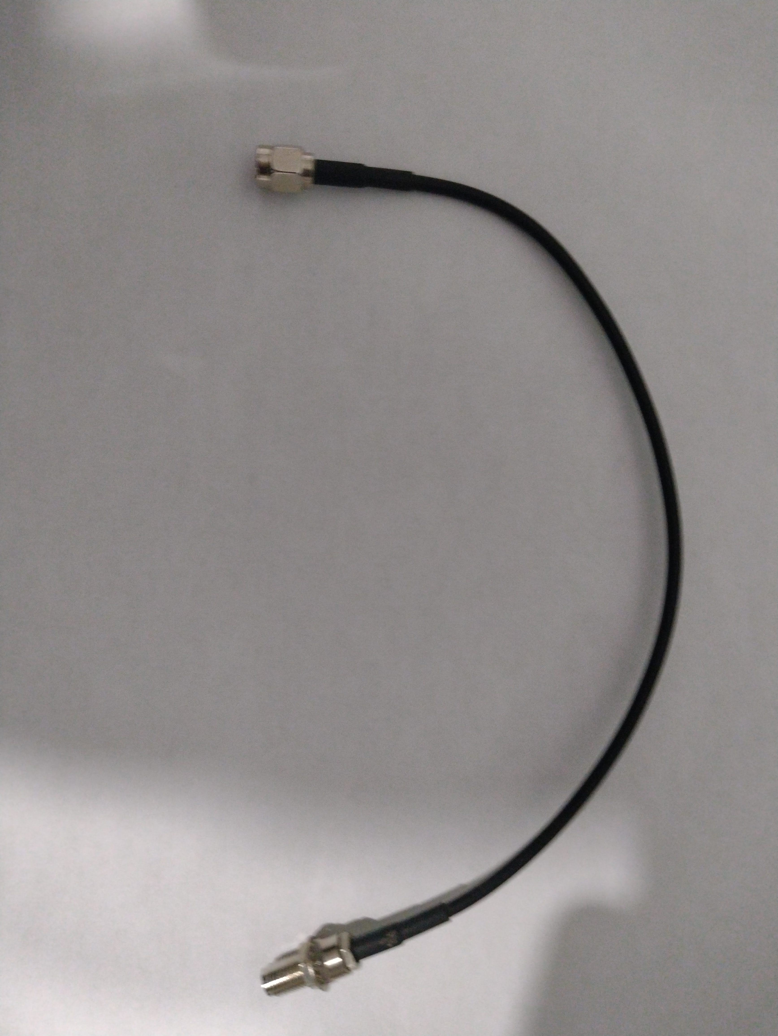
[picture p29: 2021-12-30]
how_to_docs/photos/female_to_female_connector.jpg

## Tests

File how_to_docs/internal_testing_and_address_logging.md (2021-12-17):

# 1. Introduction
This document was created mostly for myself but it can certainly be used by anyone wanting to log the addresses of DS18B20s.

# 2. Getting to it
## 2.1 Assemble circuit
Assemble a simple circuit connecting the DS18B20 to an Arduino (Uno, mkr, mega) with a 4.7 K Ohm between the data pin and the VCC pin. After this is done plug in the Arduino while running the OneWireSearch example which can be found at the following link: https://github.com/milesburton/Arduino-Temperature-Control-Library/blob/master/examples/oneWireSearch/oneWireSearch.ino.

## 2.2 Record Adress
Now write that Adress on the tag and put it on that DS18B20's tag to be put on the outside of its bag. Also tag it with the location of it in the bin (bottom, middle, or top).

## 2.3 Repeat 3 times
Repeat 2.1 and 2.2 three times so they are done a total of 4 times.

## 2.4 Test Addresses
Use the code located at code/testing_code to check if the addresses recorded are correct. Check to make sure each is reporting right by warming one or two with hands and observing the temperature change.

# 3. Conclusion
This should allow myself and possibly others to record the correct addresses of DS18B20 sensors.

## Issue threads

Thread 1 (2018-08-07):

Temperature Sensor

PhysicsUofRAUI, 2018-08-07:
Is a infrared sensor (contactless) needed? I initially thought this would be best since it would isolate the sensor from the grain, dust and pressure from having so much grain in the bin.

Will these issues bother the sensor or is using a regular and cheaper sensor the better option?

Here is the two sensors I have found online so far (for reference):

- (https://www.sparkfun.com/products/9570)
- (https://www.gadgetstrading.nl/ldtr-wg0091-ir-infrared-temperature-module-sensor-for-arduino.html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)

PhysicsUofRAUI, 2019-02-15:
It has been decided that the DHT 22 sensor will be used.

Closed 2019-02-15.

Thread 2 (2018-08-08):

Transmitter Receiver Module

PhysicsUofRAUI, 2018-08-08:
This is the transmitter-receiver module that I think may be good for the Arduino to communicate with the Raspberry Pi.

It is used in this instructable
https://www.instructables.com/id/RF-315433-MHz-Transmitter-receiver-Module-and-Ardu/

Here is where I bought mine
https://www.aliexpress.com/item/Brandnew-1x-315Mhz-RF-Transmitter-and-Receiver-Link-Set-for-Arduino-ARM-MCU-WL/32222944277.html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

Is there any better ones out there or a better way to solve this issue?

PhysicsUofRAUI, 2019-02-15:
@AcrobatBird Mentioned that there are some transmitters that can transmit much longer than this one. Here is a link to one he found [https://www.banggood.com/1100-Meter-Long-Distance-NRF24L01PALNA-Wireless-Module-With-Antenna-p-1057170.html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]

PhysicsUofRAUI, 2020-10-25:
Currently not too relevant, but I will leave it up.

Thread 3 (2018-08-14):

Code For Transferring data from Arduino to Raspberry Pi

PhysicsUofRAUI, 2018-08-14:
There will need to be some code written for sending the data, that is collected from the sensors by the Arduino, to the Raspberry Pi (under the current plan). The way this is currently going to be done is with the following [RF Link Kit](https://www.mouser.be/ProductDetail/713-113060000) .

PhysicsUofRAUI, 2018-08-14:
In this instructable they used a similar link kit but connected to arduinos instead
https://www.instructables.com/id/RF-315433-MHz-Transmitter-receiver-Module-and-Ardu/

This instructable involves the use of a similar receiver to receive information like this with a raspberry pi.
https://www.instructables.com/id/Super-Simple-Raspberry-Pi-433MHz-Home-Automation/

This could be useful when completing this issue

PhysicsUofRAUI, 2018-08-15:
Here is a couple links to help with the raspberry pi code
- https://www.princetronics.com/how-to-read-433-mhz-codes-w-raspberry-pi-433-mhz-receiver/
- https://www.raspberrypi.org/forums/viewtopic.php?t=82906

PhysicsUofRAUI, 2018-08-15:
Here is some code I have written to transmit the data. Pretty simple but I think it should work
``
/*
By: Kody Rogers
Date: 15/8/2018

Purpose: This block of code was written to transmitt code to a Raspberry Pi
in connection with the development of a system to monitor grain temperature
in a bin.

Documentation: Some extra Documentation

      The library being used to send the messages
          http://www.airspayce.com/mikem/arduino/RadioHead/index.html

*/
#include <RH_ASK.h>
#include <SPI.h> // Not actually used but needed to compile

char *sensor_one;
char *sensor_two;
char *sensor_three;

/*
Sets
 	speed = 2000,
	reciever pin = 11,
  transmitter pin = 12,

  Next two are to now whether to transmitt or not
	pttPin = 10,
 	pttInverted = false
*/
RH_ASK driver(2000, 2, 12, 11);

void setup() {
  Serial.begin(9600);
  pinMode(11,OUTPUT);

  // Set pin 11 to high so we will always transmitt
  digitalWrite(11, HIGH)

  if (!driver.init()){
    Serial.println("init failed");
  }
}

void loop() {
  /*
  The next three blocks of code get the data (this will not work right now as the
  code to get the data will have to be added later), sends it, then waits. The code
  does compile with the arduino compiler right now but only if you comment out the first
  line (looks like this 'sensor_one = getData(1);'), but it has not been tested. A test could be done by
  uncommenting the first line of each (looks like this '//sensor_one = "hello";') then
  the code should send "hello" all the time as long as it is wired correctly
  */
  //sensor_one = "hello";
  sensor_one = getData(1);
  driver.send((uint8_t *)sensor_one, strlen(sensor_one));
  driver.waitPacketSent();

  // sensor_two = "hello";
  sensor_two = getData(2);
  driver.send((uint8_t *)sensor_two, strlen(sensor_two));
  driver.waitPacketSent();

  //sensor_three = "hello";
  sensor_three = getData(3);
  driver.send((uint8_t *)sensor_three, strlen(sensor_three));
  driver.waitPacketSent();

  delay(1000);
}

PhysicsUofRAUI, 2020-10-25:
Currently not too relevant, but I will leave it up.

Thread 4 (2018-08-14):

Displaying the information (or dispatching on Raspberry Pi)

PhysicsUofRAUI, 2018-08-14:
This is where the discussion about the how the information from the Arduino will be used by the Raspberry Pi will happen.

Should the Raspberry Pi just receive the information and display it on a terminal interface? Should a better display be made? Should an ascii fill be made that logs the data continuously? Should there be email (or other) alerts?

PhysicsUofRAUI, 2020-10-25:
Currently not too relevant, but I will leave it up.

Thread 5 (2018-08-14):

Power for the Arduino

PhysicsUofRAUI, 2018-08-14:
How should we power the Arduino? They may be in a place not so accessible to outlets, so this should be a discussion.

Should it be battery pack? If so, how many? One for each or just a hub where all are connected to?

PhysicsUofRAUI, 2018-08-14:
I think battery pack would be best and I just checked with my power bank to make sure it works with the Arduino and it does :smile: .

It might be better to design something more specific to the problem though :thinking: . I am not sure though but it is just each Arduino with its own power bank may be overkill

PhysicsUofRAUI, 2019-02-15:
It has been decided that a power bank like this one https://www.amazon.ca/Poweradd-Pilot-X7-compatible-Smartphone/dp/B018I30H30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, old cell phone batteries made into a power bank like in this tutorial https://www.instructables.com/id/Make-A-Cheap-Lithium-Battery-Pack/, or a simple 9 V battery would probably be best.

PhysicsUofRAUI, 2019-06-07:
Here is a tutorial on how to set up a lipoly battery to charge from a solar panel https://learn.adafruit.com/usb-dc-and-solar-lipoly-charger/overview

PhysicsUofRAUI, 2020-10-25:
Current version plugs into a wall plugin, so until everything gets well and sorted for that I will close this issue

Closed 2020-10-25.

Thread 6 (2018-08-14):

Code for collecting data from temp sensors with Arduino

PhysicsUofRAUI, 2018-08-14:
There will have to be code written for the Arduino to collect the data from the sensors. This is just for the collection of the raw data and then the transfering to celcius.

PhysicsUofRAUI, 2018-08-15:
This is a link to the temperature sensor https://www.mouser.be/ProductDetail/482-90614ESFBAA000TU
and here is a link to the data sheet https://www.mouser.be/datasheet/2/734/MLX90614-Datasheet-Melexis-953298.pdf

PhysicsUofRAUI, 2018-10-14:
Here is a link that more properly describes how to hook up the sensor. https://learn.sparkfun.com/tutorials/mlx90614-ir-thermometer-hookup-guide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

Closed 2018-10-06.

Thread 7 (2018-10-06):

Choose which sensor to collect data

PhysicsUofRAUI, 2018-10-06:
The current code just retrieves sensors from a sensor, but no particular one. This is problematic since we have three sensors that each Arduino is responsible for.

Because of this, we need some way to determine which sensor we should be collecting information from.

The following is a link to the library currently being used (https://github.com/adafruit/Adafruit-MLX90614-Library)

PhysicsUofRAUI, 2018-10-14:
It seems that the sensor has to be connected to specific input pins, so I do not think it will be possible.

PhysicsUofRAUI, 2018-10-25:
Here is a thread I started on adafruit
https://forums.adafruit.com/viewtopic.php?f=8&t=141864

PhysicsUofRAUI, 2018-10-26:
here is a link to information about an i2c multiplexer
https://learn.adafruit.com/adafruit-tca9548a-1-to-8-i2c-multiplexer-breakout/overview

https://learn.adafruit.com/adafruit-tca9548a-1-to-8-i2c-multiplexer-breakout/featured_products

So I think that using multiple sensors is doable after all

PhysicsUofRAUI, 2019-02-15:
It has been decided that the DHT 22 Sensor(https://learn.adafruit.com/dht/overview) will be used as the sensor. This is mostly because it is cheap, measures both humidity and temperature, and a non-contact method is not needed.

Closed 2019-02-15.

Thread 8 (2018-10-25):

Sending data between arduinos via wire communication

PhysicsUofRAUI, 2018-10-25:
This may be a good idea since when in the bin the radio may not work well.

A link to this end
https://www.arduino.cc/en/Tutorial/MasterReader

PhysicsUofRAUI, 2019-02-15:
This does not fit in with the current design plans.

Closed 2019-02-15.

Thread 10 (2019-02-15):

Wifi

PhysicsUofRAUI, 2019-02-15:
@AcrobatBird mentioned that we could just use a router at the house without any internet. This would allow the raspberry pi and arduino be connected via WiFi. It would only work for bins in a yard however.

PhysicsUofRAUI, 2021-09-05:
With the MKR boards this can be done by using the MKR WiFi which is actually the one in use at my farm

Closed 2021-09-05.

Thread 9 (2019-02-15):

Heat and Moisture Problems

PhysicsUofRAUI, 2019-02-15:
The Arduino and senors will be outside in temperatures dipping down as low as -45 C :snowflake:. There is also going to be large temperature fluctations between night and day, so that will bring up the problem of condensation.

PhysicsUofRAUI, 2019-02-15:
I think making an enclosure out of wood with a waterproof top would protect the enclusure from rain while also letting moisture in and out. Then a small resistor can be used to heat the inside of the enclosure as well. Here is a link found be @AcrobatBird that gives a lot of insight of stuff like this https://forum.arduino.cc/index.php?topic=129212.0

PhysicsUofRAUI, 2020-10-25:
Ended up using a junction box. In particular this junction box: https://www.amazon.ca/gp/product/B075DG55KS/ref=ppx_yo_dt_b_asin_title_o02_s00?ie=UTF8&psc=1

Closed 2020-10-25.

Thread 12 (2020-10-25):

Create Three different pieces of code

PhysicsUofRAUI, 2020-10-25:
One piece of code to control sensors in a single bin, one to control sensors in two bins, and one more to control sensors in three bins. For now, just write it so that it is an alert system.

PhysicsUofRAUI, 2020-10-31:
We actually need 4 since the MKR has 15 pins it can handle up to 5 bins, but that would use all the pins so I am going to just use 12 of those pins

PhysicsUofRAUI, 2020-11-01:
Created four different pieces of code but would like a chance to test them before closing the issue

Closed 2021-09-05.

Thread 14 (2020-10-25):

Arduino Cloud

PhysicsUofRAUI, 2020-10-25:
This is going to be the next thing added (after the new code and how-to manual is added). Use the Arduino cloud to log the data in a google sheets so that the farmer can view the trend.

PhysicsUofRAUI, 2021-09-05:
Have the cloud connected now, and the google sheets thing may be added at a later date in its own issue.

Closed 2021-09-05.

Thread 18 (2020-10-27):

Create Tests

PhysicsUofRAUI, 2020-10-27:
Need to add some automated tests to verify the code works before it is deployed. Testing the functions to be created while solving #17 will be relatively simple, but testing behaviour with different temperature inputs may be difficult. AUnit or ArduinoUnit may be helpful.

PhysicsUofRAUI, 2020-10-27:
Using software such as described in this Instructables post is a possibility, but not preferable. https://www.instructables.com/How-to-Test-Arduino-Cirtcuit-and-Code-Online/

PhysicsUofRAUI, 2020-10-30:
All done!

Closed 2020-10-30.

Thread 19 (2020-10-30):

Create new test using custom library

PhysicsUofRAUI, 2020-10-30:
I'd like to have a test ready that I can deploy in and verify the new library works well in the field

PhysicsUofRAUI, 2020-11-01:
Test is written but I won't close until it I wire it up and test it

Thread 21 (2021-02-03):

Create a testing setup.

PhysicsUofRAUI, 2021-02-03:
Create a testing regime to test the functionality of the cable.

Put tests that are meant to test the actual code in a different folder.

PhysicsUofRAUI, 2021-09-05:
While testing the cable the collection of the addresses of the one wire sensors should also be done

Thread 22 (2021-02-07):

Edit cable design

PhysicsUofRAUI, 2021-02-07:
Need to place filter capcitors most likely and perhaps change assembly methods.

Use this method to find the right design (at the start)
1. One sensor at the end with of a 30 m wire with the capacitor near it.
- if it does not work put a capacitor near the arduino too
- if that does not work remove the capacitor close to the sensor.
2. Add the other two sensors incrementally (change up capacitor positions somewhat logically).
3. Once it is working create a circuit diagram.

khanafin, 2021-03-24:
Interesting Project...  I have developed a similar system for collecting temps underwater in lakes.  I use an ESP32 to send the data from TI tmp-107 sensors to a server via wifi or cellular 2G/3G/LTE.  I have 15-20 sensors monitoring the thermocline 150m offshore.  Sample data:
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
Let me know if you are interested in talking.
Karl Hanafin
karl@hanafins.com

PhysicsUofRAUI, 2021-07-30:
Using the DS18B20 sensors for the most part now so this is not needed anymore

Closed 2021-07-30.

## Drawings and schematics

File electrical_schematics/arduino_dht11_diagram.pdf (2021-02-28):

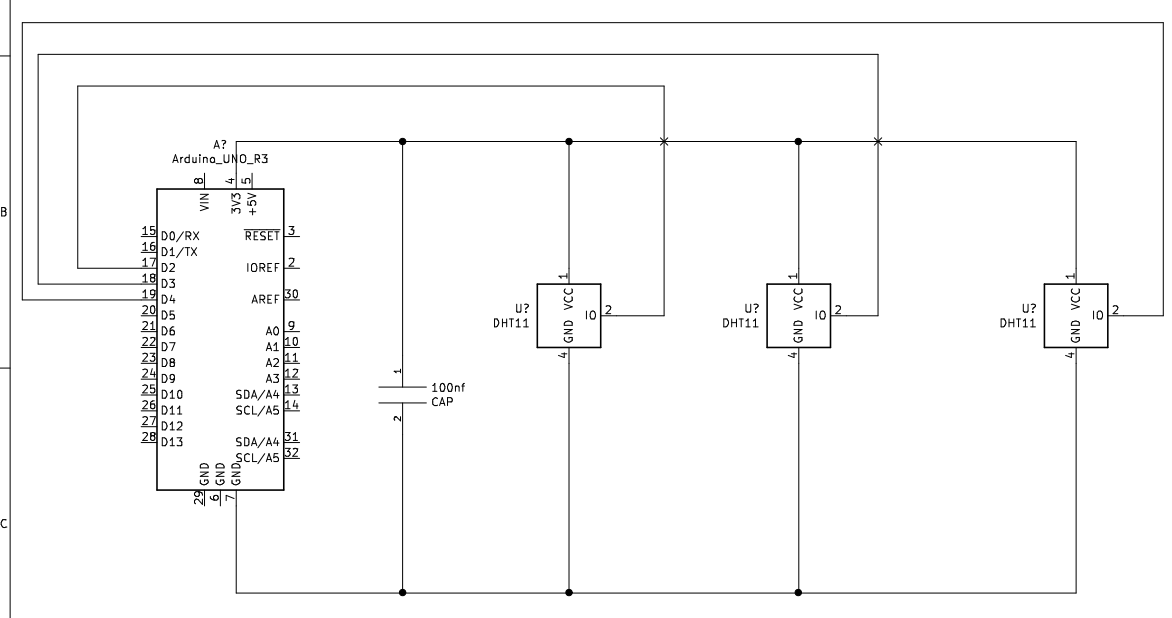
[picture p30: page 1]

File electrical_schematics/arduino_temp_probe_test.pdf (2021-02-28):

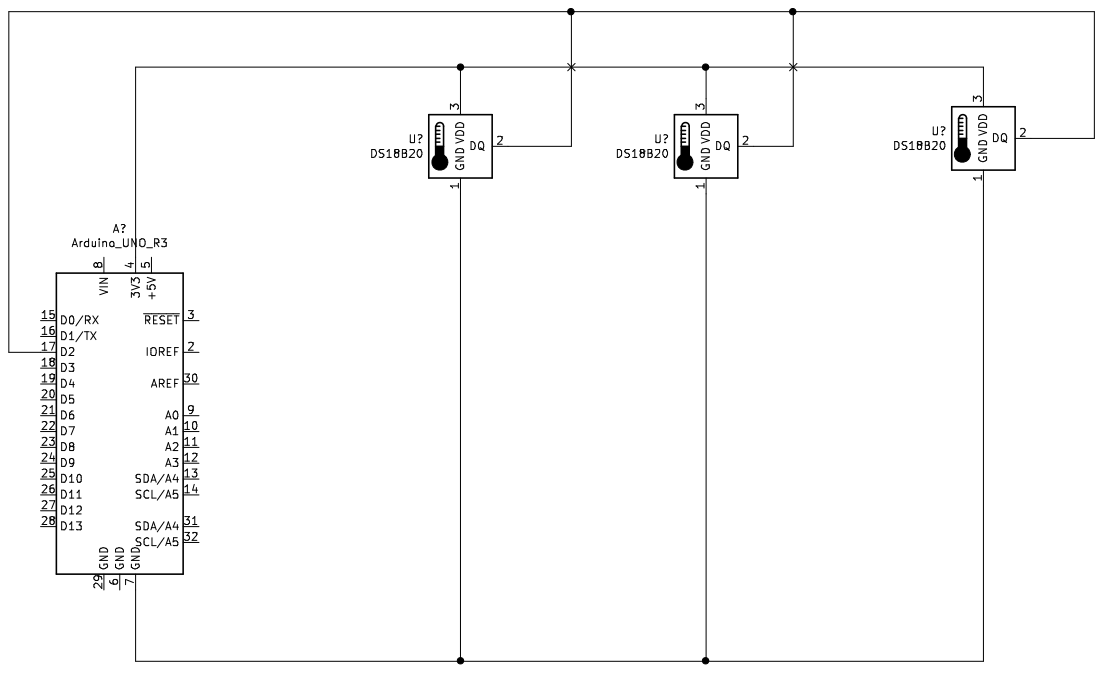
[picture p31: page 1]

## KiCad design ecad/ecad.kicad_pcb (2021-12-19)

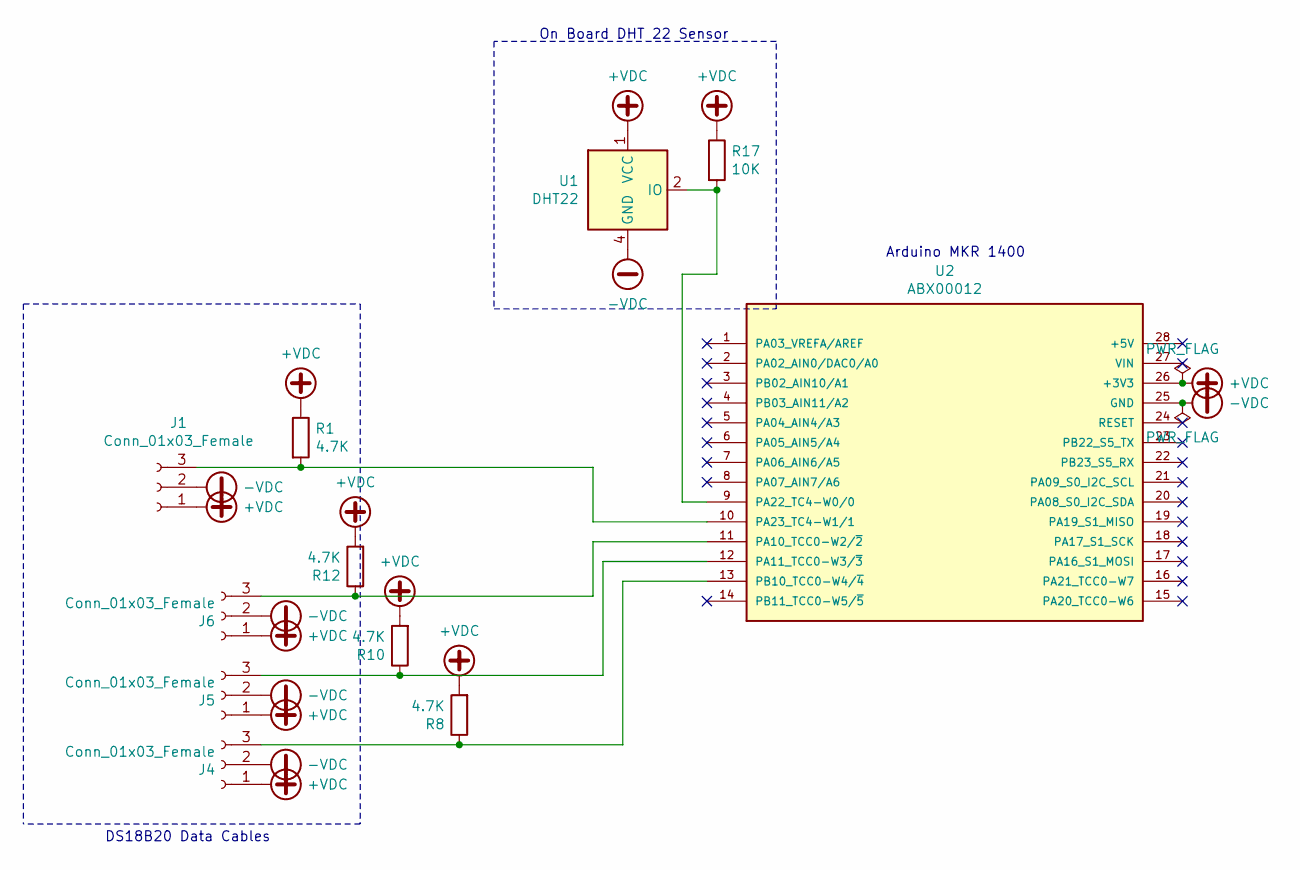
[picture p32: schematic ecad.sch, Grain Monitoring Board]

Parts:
J1, J4, J5, J6: Conn_01x03_Female; Wago_734-133_1x03_P5.0mm_Vertical
R1, R8, R10, R12: 4.7K; R_Axial_DIN0207_L6.3mm_D2.5mm_P7.62mm_Horizontal
R17: 10K; R_Axial_DIN0207_L6.3mm_D2.5mm_P7.62mm_Horizontal
U1: DHT22; Aosong_DHT11_5.5x12.0_P2.54mm
U2: ABX00012; ARDUINO_ABX00012; PARTREV 5

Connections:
+VDC: J1.1, J4.1, J5.1, J6.1, R1.1, R8.2, R10.2, R12.2, R17.1, U1.1 (VCC), U2.26 (+3V3)
-VDC: J1.2, J4.2, J5.2, J6.2, U1.4 (GND), U2.25 (GND)
unnamed: J1.3, R1.2, U2.10 (PA23_TC4-W1/1)
unnamed: J4.3, R8.1, U2.13 (PB10_TCC0-W4/~4)
unnamed: J5.3, R10.1, U2.12 (PA11_TCC0-W3/~3)
unnamed: J6.3, R12.1, U2.11 (PA10_TCC0-W2/~2)
unnamed: R17.2, U1.2 (IO), U2.9 (PA22_TC4-W0/0)

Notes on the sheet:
Arduino MKR 1400
DS18B20 Data Cables
On Board DHT 22 Sensor

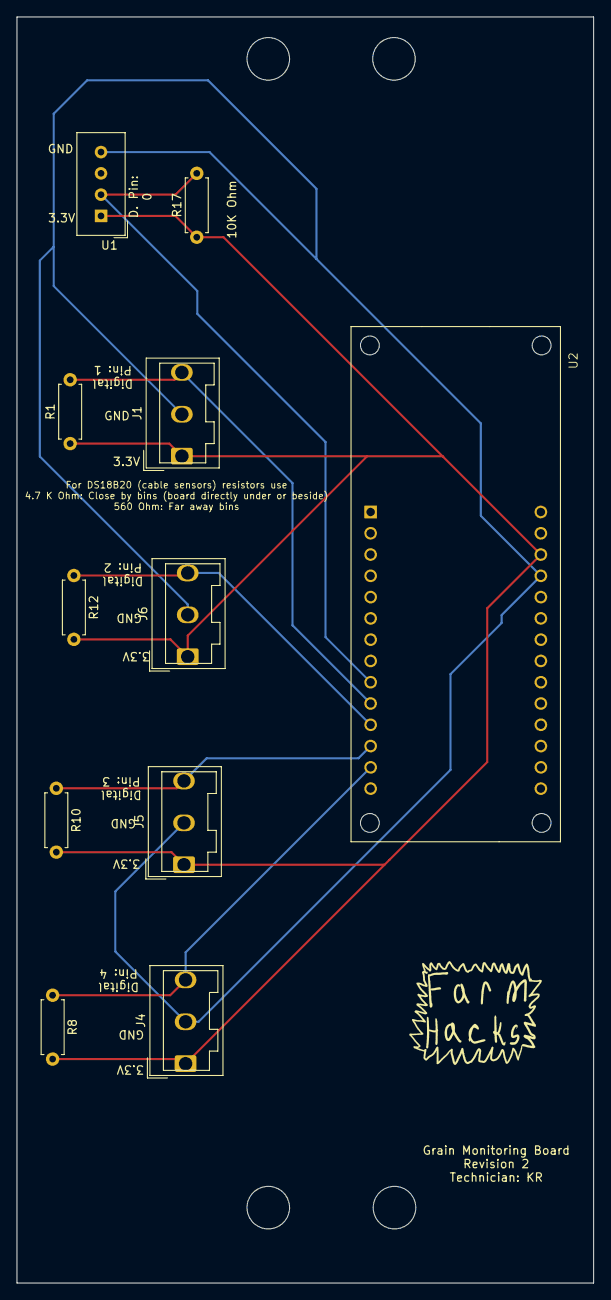
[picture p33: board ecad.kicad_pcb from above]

Board: 2 copper layers, 68.8 x 151.1 mm, 11 parts (0 on the bottom side), 7 nets.

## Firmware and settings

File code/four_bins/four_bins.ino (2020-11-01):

// Include all the needed libraries
#include <MKRGSM.h>
#include <bin_sensor.hpp>

// Set up everything for the cellular device to work

// modem verification object
GSMModem modem;

// initialize the library instance
GSM gsmAccess;
GSM_SMS sms;

// everything to control the sensors
// bin one
#define DHTPIN1            0
#define DHTPIN2            1
#define DHTPIN3            2

// bin two
#define DHTPIN4            3
#define DHTPIN5            4
#define DHTPIN6            5

// bin three
#define DHTPIN7            6
#define DHTPIN8            7
#define DHTPIN9            8

// bin four
#define DHTPIN10            9
#define DHTPIN11            10
#define DHTPIN12            11

#define DHTTYPE           DHT22

// bin one
DHT_Unified dht1(DHTPIN1, DHTTYPE);
DHT_Unified dht2(DHTPIN2, DHTTYPE);
DHT_Unified dht3(DHTPIN3, DHTTYPE);

// bin two
DHT_Unified dht4(DHTPIN4, DHTTYPE);
DHT_Unified dht5(DHTPIN5, DHTTYPE);
DHT_Unified dht6(DHTPIN6, DHTTYPE);


// bin three
DHT_Unified dht7(DHTPIN7, DHTTYPE);
DHT_Unified dht8(DHTPIN8, DHTTYPE);
DHT_Unified dht9(DHTPIN9, DHTTYPE);

// bin four
DHT_Unified dht10(DHTPIN10, DHTTYPE);
DHT_Unified dht11(DHTPIN11, DHTTYPE);
DHT_Unified dht12(DHTPIN12, DHTTYPE);

float result = 0.0;


// bin one
BinSensor bin_sensor1((float)0.5);
BinSensor bin_sensor2((float)0.5);
BinSensor bin_sensor3((float)0.5);

// bin two
BinSensor bin_sensor4((float)0.5);
BinSensor bin_sensor5((float)0.5);
BinSensor bin_sensor6((float)0.5);

// bin three
BinSensor bin_sensor7((float)0.5);
BinSensor bin_sensor8((float)0.5);
BinSensor bin_sensor9((float)0.5);

// bin four
BinSensor bin_sensor10((float)0.5);
BinSensor bin_sensor11((float)0.5);
BinSensor bin_sensor12((float)0.5);

void setup() {
  // put your setup code here, to run once:
  dht1.begin();
  dht2.begin();
  dht3.begin();

  // connection state
  bool connected = false;
  bool flag = true;

  while(flag)
  {
    // start modem test (reset and check response)
    if (modem.begin()) {
      flag = false;
    } else {
    }
  }

  // Start GSM shield
  // If your SIM has PIN, pass it as a parameter of begin() in quotes
  while (!connected) {
    if (gsmAccess.begin("0000") == GSM_READY) {
      connected = true;
    } else {
      delay(1000);
    }
  }

  sms.beginSMS("your-phone-number");
  sms.print("Connected!");
  sms.endSMS();
}

void loop() {
  // put your main code here, to run repeatedly:

  /*
   * Check the sensors in the first bin
   */

  result = bin_sensor1.check_sensor(dht1);

  if (result < 0)
  {
    sms.beginSMS("your-phone-number");
    sms.print("Sensor Failure");
    sms.endSMS();
  }
  else if (result > 0)
  {
    sms.beginSMS("your-phone-number");
    sms.print("Top of bin one has increased by ");
    sms.print(result);
    sms.endSMS();
  }

  result = bin_sensor2.check_sensor(dht2);

  if (result < 0)
  {
    sms.beginSMS("your-phone-number");
    sms.print("Sensor Failure");
    sms.endSMS();
  }
  else if (result > 0)
  {
    sms.beginSMS("your-phone-number");
    sms.print("Middle of bin one has increased by ");
    sms.print(result);
    sms.endSMS();
  }

  result = bin_sensor3.check_sensor(dht3);

  if (result < 0)
  {
    sms.beginSMS("your-phone-number");
    sms.print("Sensor Failure");
    sms.endSMS();
  }
  else if (result > 0)
  {
    sms.beginSMS("your-phone-number");
    sms.print("Bottom of bin one has increased by ");
    sms.print(result);
    sms.endSMS();
  }


  /*
   * Check the sensors in the second bin
   */
   result = bin_sensor4.check_sensor(dht4);

  if (result < 0)
  {
    sms.beginSMS("your-phone-number");
    sms.print("Sensor Failure");
    sms.endSMS();
  }
  else if (result > 0)
  {
    sms.beginSMS("your-phone-number");
    sms.print("Top of bin two has increased by ");
    sms.print(result);
    sms.endSMS();
  }

  result = bin_sensor5.check_sensor(dht5);

  if (result < 0)
  {
    sms.beginSMS("your-phone-number");
    sms.print("Sensor Failure");
    sms.endSMS();
  }
  else if (result > 0)
  {
    sms.beginSMS("your-phone-number");
    sms.print("Middle of bin two has increased by ");
    sms.print(result);
    sms.endSMS();
  }

  result = bin_sensor6.check_sensor(dht6);

  if (result < 0)
  {
    sms.beginSMS("your-phone-number");
    sms.print("Sensor Failure");
    sms.endSMS();
  }
  else if (result > 0)
  {
    sms.beginSMS("your-phone-number");
    sms.print("Bottom of bin two has increased by ");
    sms.print(result);
    sms.endSMS();
  }

  /*
   * Check the sensors in the third bin
   */
   result = bin_sensor7.check_sensor(dht7);

  if (result < 0)
  {
    sms.beginSMS("your-phone-number");
    sms.print("Sensor Failure");
    sms.endSMS();
  }
  else if (result > 0)
  {
    sms.beginSMS("your-phone-number");
    sms.print("Top of bin three has increased by ");
    sms.print(result);
    sms.endSMS();
  }

  result = bin_sensor8.check_sensor(dht8);

  if (result < 0)
  {
    sms.beginSMS("your-phone-number");
    sms.print("Sensor Failure");
    sms.endSMS();
  }
  else if (result > 0)
  {
    sms.beginSMS("your-phone-number");
    sms.print("Middle of bin three has increased by ");
    sms.print(result);
    sms.endSMS();
  }

  result = bin_sensor9.check_sensor(dht9);

  if (result < 0)
  {
    sms.beginSMS("your-phone-number");
    sms.print("Sensor Failure");
    sms.endSMS();
  }
  else if (result > 0)
  {
    sms.beginSMS("your-phone-number");
    sms.print("Bottom of bin three has increased by ");
    sms.print(result);
    sms.endSMS();
  }

  /*
   * Check the sensors in the fourth bin
   */
   result = bin_sensor10.check_sensor(dht10);

  if (result < 0)
  {
    sms.beginSMS("your-phone-number");
    sms.print("Sensor Failure");
    sms.endSMS();
  }
  else if (result > 0)
  {
    sms.beginSMS("your-phone-number");
    sms.print("Top of bin four has increased by ");
    sms.print(result);
    sms.endSMS();
  }

  result = bin_sensor11.check_sensor(dht11);

  if (result < 0)
  {
    sms.beginSMS("your-phone-number");
    sms.print("Sensor Failure");
    sms.endSMS();
  }
  else if (result > 0)
  {
    sms.beginSMS("your-phone-number");
    sms.print("Middle of bin four has increased by ");
    sms.print(result);
    sms.endSMS();
  }

  result = bin_sensor12.check_sensor(dht12);

  if (result < 0)
  {
    sms.beginSMS("your-phone-number");
    sms.print("Sensor Failure");
    sms.endSMS();
  }
  else if (result > 0)
  {
    sms.beginSMS("your-phone-number");
    sms.print("Bottom of bin four has increased by ");
    sms.print(result);
    sms.endSMS();
  }

  // wait for 12 hours
  delay(43200000);
}

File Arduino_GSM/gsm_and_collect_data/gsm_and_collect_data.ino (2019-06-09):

// Include the GSM library
#include <MKRGSM.h>

#include <DHT.h>
#include <DHT_U.h>

#include <Adafruit_Sensor.h>

#define DHTPIN1            2
#define DHTPIN2            3
#define DHTPIN3            4

#define DHTTYPE           DHT22

DHT_Unified dht1(DHTPIN1, DHTTYPE);
DHT_Unified dht2(DHTPIN2, DHTTYPE);
DHT_Unified dht3(DHTPIN3, DHTTYPE);

float temp1 = 0;
float temp2 = 0;
float temp3 = 0;

float cur_temp1;
float cur_temp2;
float cur_temp3;

int difference;

/*
Purpose: To get the temperature when it fails. This function will first be called when
  the primary attempt to attain the temperature failed, and it will then be recusivly
  called until such time the temperature is attained.
Parameters:
  sensor_needed: This is an object that represents the sensor that failed to
    read.
Variables:
  new_event: The event object as defined in the DHT libraries. This is a variable
    used to collect information from an event. It will be used in this function
    to get the temperature information.

Returns:
  temperature: a float that is the temperature that was read.
*/
float getTemperatureInCaseOfError(DHT_Unified sensor_needed)
{
  sensors_event_t new_event;

  delay(4000);

  sensor_needed.temperature().getEvent(&new_event);

  float temperature = new_event.temperature;

  if (isnan(temperature))
  {
    temperature = getTemperatureInCaseOfError(sensor_needed);
  }

  return temperature;
}




// initialize the library instance
GSM gsmAccess;
GSM_SMS sms;

void setup() {
  // initialize serial communications and wait for port to open:
  Serial.begin(9600);
  while (!Serial) {
    ; // wait for serial port to connect. Needed for native USB port only
  }

  Serial.println("SMS Messages Sender");

  // connection state
  bool connected = false;

  // Start GSM shield
  // If your SIM has PIN, pass it as a parameter of begin() in quotes
  while (!connected) {
    if (gsmAccess.begin(0000) == GSM_READY) {
      connected = true;
    } else {
      Serial.println("Not connected");
      delay(1000);
    }
  }

  Serial.println("GSM initialized");

  Serial.begin(9600);

  dht1.begin();
  dht2.begin();
  dht3.begin();

  sensor_t sensor;

  Serial.println("All sensors initialized");
}



/*
This is the loop. It will get measurements from all three sensors, display
the temperature, and the difference from the previous value.

It will then wait 10 seconds to do the next set of measurements then it will repeat.
*/
void loop() {
  // Get temperature event
  sensors_event_t event1;
  dht1.temperature().getEvent(&event1);

  if (isnan(event1.temperature)) {
    // try to get the event again
    float temperature = getTemperatureInCaseOfError(dht1);

    // find the difference between current value and previous value
    difference = temperature - temp1;

    // When getting the event is a success print the temperature
    sms.beginSMS("13069218495");
    sms.print("Hello there");
    sms.print("temperature 1: ");
    sms.print(temperature);
    sms.print(", difference: ");
    sms.println(difference);
    sms.endSMS();

    // update the temp1 variable
    temp1 = temperature;
  }
  else {
    // Get the current temperature from sensor 1
    float temperature = event1.temperature;

    // find the difference between current value and previous value
    difference = temperature - temp1;

    // print the current temperature and the difference from the
    // previous temperature
    sms.beginSMS("13069218495");
    sms.print("Hello there");
    sms.print("temperature 1: ");
    sms.print(temperature);
    sms.print(", difference: ");
    sms.println(difference);
    sms.endSMS();

    // update temp 1
    temp1 = cur_temp1;
  }

  // Get temperature event and print its value.
  sensors_event_t event2;
  dht2.temperature().getEvent(&event2);
  if (isnan(event2.temperature)) {
    // try to get the event again
    float temperature = getTemperatureInCaseOfError(dht2);

    // find the difference between current value and previous value
    difference = temperature - temp2;

    // When getting the event is a success print the temperature
    sms.beginSMS("13069218495");
    sms.print("Hello there");
    sms.print("temperature 2: ");
    sms.print(temperature);
    sms.print(", difference: ");
    sms.println(difference);
    sms.endSMS();

    // update the temp1 variable
    temp2 = temperature;
  }
  else {
    // Get the current temperature from sensor 2
    float temperature = event2.temperature;

    // find the difference between current value and previous value
    difference = temperature - temp2;

    // When getting the event is a success print the temperature
    sms.beginSMS("13069218495");
    sms.print("Hello there");
    sms.print("temperature 2: ");
    sms.print(temperature);
    sms.print(", difference: ");
    sms.println(difference);
    sms.endSMS();

    // update the temp2 variable
    temp2 = cur_temp2;
  }

  // Get temperature event and print its value.
  sensors_event_t event3;
  dht3.temperature().getEvent(&event3);
  if (isnan(event3.temperature)) {
    // try to get the event again
    float temperature = getTemperatureInCaseOfError(dht3);

    // find the difference between current value and previous value
    difference = temperature - temp3;

    // When getting the event is a success print the temperature
    sms.beginSMS("13069218495");
    sms.print("Hello there");
    sms.print("temperature 3: ");
    sms.print(temperature);
    sms.print(", difference: ");
    sms.println(difference);
    sms.endSMS();

    // update the temp3 variable
    temp3 = temperature;
  }
  else {
    // Get the current temperature from sensor 3
    float temperature = event3.temperature;

    // find the difference between current value and previous value
    difference = cur_temp3 - temp3;

    // When getting the event is a success print the temperature
    sms.beginSMS("13069218495");
    sms.print("Hello there");
    sms.print("temperature 3: ");
    sms.print(temperature);
    sms.print(", difference: ");
    sms.println(difference);
    sms.endSMS();

    // update the temp3 variable
    temp3 = cur_temp3;
  }

  // Delay between measurements.
  delay(30000);
}

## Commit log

2018-10-06 First bit of code. Even if it does not work
    [code_to_retrieveTemp_andSendViaRadio.cpp]
2018-10-06 specified do not have way to select sensor
2018-12-04 Update readme.md
    Gave descriptions of three separate versions that could be made. Also added the talk about the DHT 22 sensor.
2018-12-31 made test code to retreive data from three sensors
2019-02-17 code to control three sensors. Still need to add difference check
2019-02-17 found some code on a tutorial that uses gsm module and the dht sensor
2019-02-17 code from tutorial being able to run from arduino editor
2019-06-09 axed that I will be making prototype this weekend
2019-06-24 Created a test for battery and sensors. Updated relevant readme
2019-06-28 added low power code
2020-10-27 code to monitor a single bin with three sensors
2021-01-24 drafted the temp cable tutorial
2021-01-30 added most of the photos to temperature cable tutorial
2021-01-30 added some code that will be used to test new temperature cables com uno
2021-02-01 added one more photo to the cable doc
2021-02-28 Added the two files that run the Arduino Cloud code
2021-02-28 add electrical schematic using the dfrobot temp probe in test
2021-02-28 add schematic using the dht11 sensor (temporary)
2021-04-24 update code to send email alerts when temperature rises
2021-05-23 add files to create first iteration of pcb
    [ecad.kicad_pcb, ecad.sch]
2021-05-23 update gitignore to ignore uneeded pcb files
2021-06-04 add two bin code using ds18b20 sensors
2021-06-12 add more comments to the schematic
    [ecad.sch]
2021-07-23 add images to temperature cable doc
2021-07-26 make pcb smaller and only one wire for each cable
    [ecad.kicad_pcb, ecad.sch]
2021-07-26 create initial DS18B20 cable tutorial.
2021-08-06 update ds18b20 temperature cable how to
2021-08-06 update pcb board
    [ecad.kicad_pcb]
2021-08-06 add four bin code using the ds18b20 cables on the original pcb
2021-08-27 updated pcb to use 3.3V instead of 5V
    [ecad.kicad_pcb, ecad.sch]
2021-08-27 add some pcb files to gitignore
2021-08-27 switch from 5V to 3.3V
2021-08-28 add ds18b20 schematic
    [ds18b20_cable_schematic.kicad_pcb, ds18b20_cable_schematic.sch]
2021-12-17 added code to get temperatures on connection so zeros are not displayed
2021-12-17 add pcb assembly doc
2021-12-17 update ds18b20 temp cable how-to
2021-12-19 update gitignore to include other gerber files
2021-12-19 add resistor values to silkscreen
    [ecad.kicad_pcb]
2021-12-27 update 4 bin 3 ds18b20 sensors per bin code.
2021-12-30 add antenna assembly booklet
2022-01-08 add PCB only instructions
